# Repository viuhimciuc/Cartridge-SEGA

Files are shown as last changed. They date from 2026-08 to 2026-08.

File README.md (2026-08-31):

# 🎮 Cartridge-SEGA: Sega Genesis Cartridge PCBs 🕹️






An open-source collection of hardware design files for **Sega Genesis / Mega Drive** cartridge PCBs (Printed Circuit Boards). Designed from scratch or reverse-engineered using **KiCad**, this repository provides schemas and layouts for creating custom cartridges, multi-game boards, and memory adapters.

---

## 📂 Repository Structure

The project is organized into several key hardware modules:

*   **`GEN-CART-171-6329A-7147A`** — Replica or custom variant of standard Sega Genesis cartridge PCBs.
*   **`GEN-CART-171-6570A`** — Re-engineered files based on the classic 171-6570A board layout.
*   **`GEN-CART-171-6570A_MultiGames`** — Modded version supporting multiple games on a single cartridge via bank switching or custom routing.
*   **`TSOP_Adapter_M29FxxxF`** — A specialized adapter board converting TSOP flash memory chips (like the M29F series) to DIP/SOP layouts suitable for retro console cartridges.

---

## 🛠️ Built With

*   [KiCad EDA](https://www.kicad.org/) — A Cross-Platform and Open Source Electronics Design Automation Suite.

---

## 📸 Gallery & Visuals

### 🔧 Component Placement / PCB Layout Preview

<p align="center">
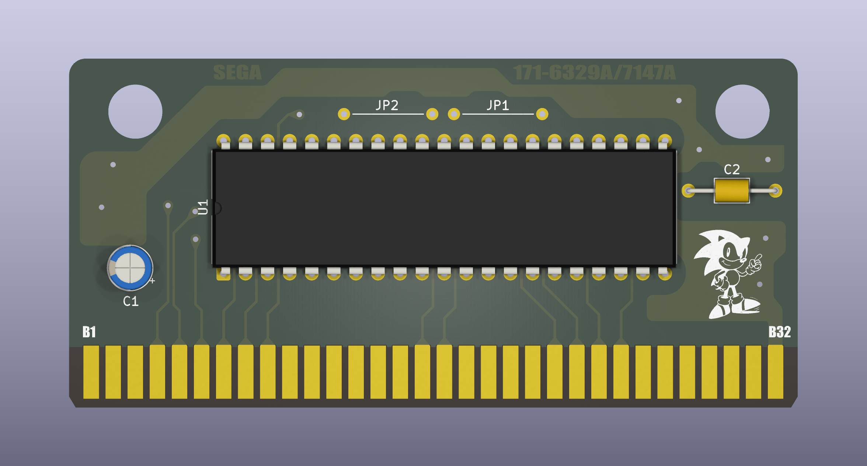
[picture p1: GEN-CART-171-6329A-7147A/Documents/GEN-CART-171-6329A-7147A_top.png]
PCB GEN-CART-171-6329A-7147A
  
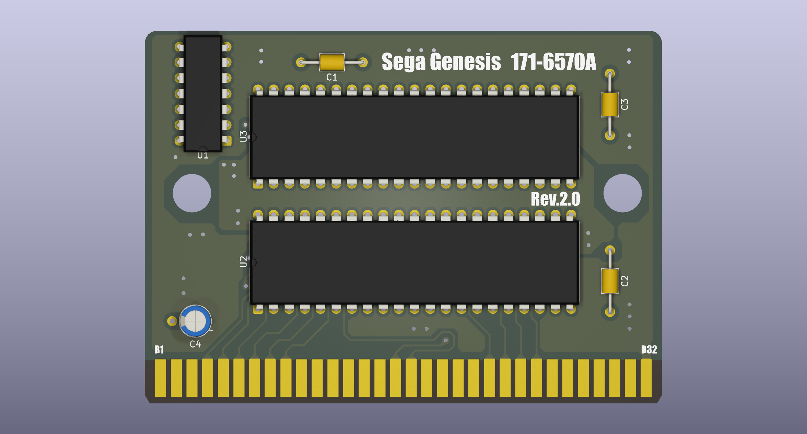
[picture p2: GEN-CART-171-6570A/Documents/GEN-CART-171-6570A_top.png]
PCB GEN-CART-171-6570A
  
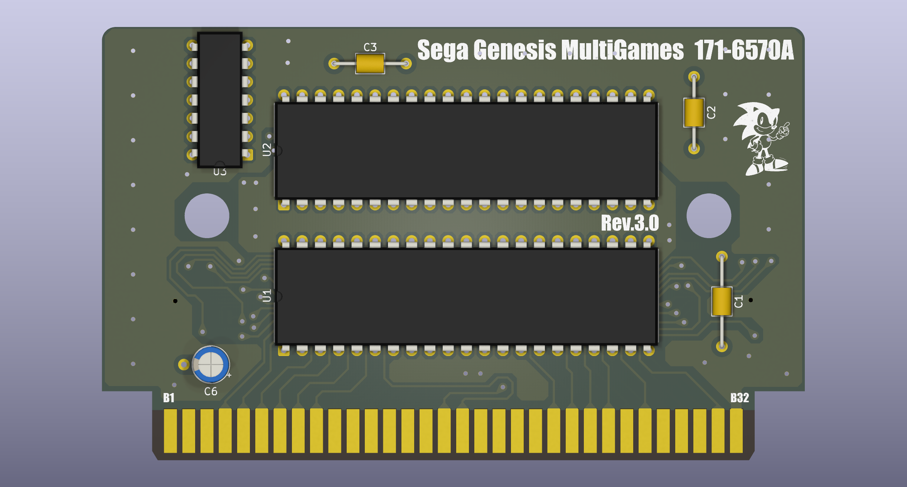
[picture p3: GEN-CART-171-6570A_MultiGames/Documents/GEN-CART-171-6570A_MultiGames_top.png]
PCB GEN-CART-171-6570A MultiGames
  
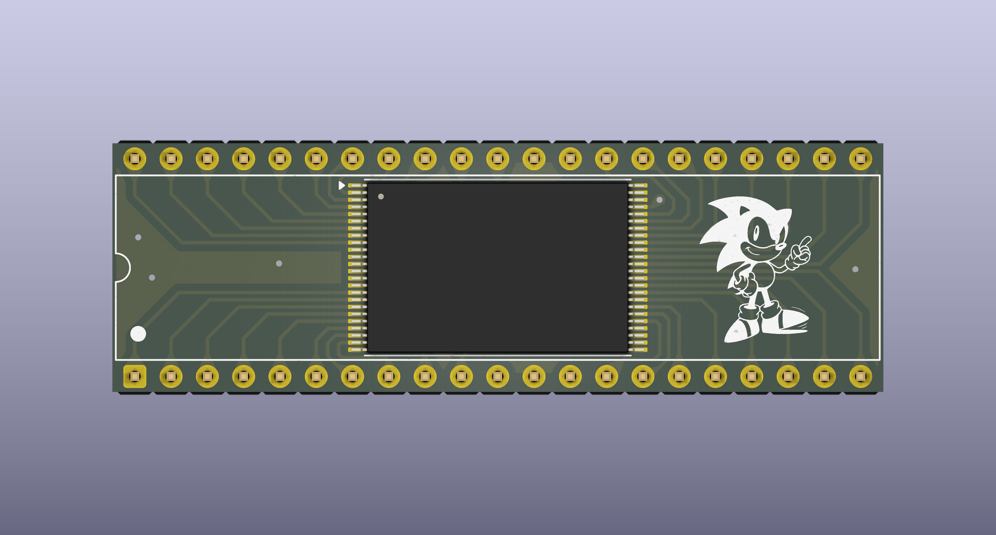
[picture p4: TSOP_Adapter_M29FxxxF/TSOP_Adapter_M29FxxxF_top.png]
PCB TSOP Adapter M29FxxxF
  
</p>

---

## 🚀 Getting Started

### 📋 Prerequisites
To open, edit, or export production files (Gerbers) from this project, you need:
*   **KiCad 7.0 or newer** (Recommended)

### 📥 Cloning the Repository
```bash
git clone https://github.com/viuhimciuc/Cartridge-SEGA.git
```

### ⚙️ How to Generate Gerber Files for Manufacturing
1. Open the `.kicad_pro` project file from any folder in KiCad.
2. Open the **PCB Editor** (`.kicad_pcb`).
3. Go to **File** -> **Fabrication Outputs** -> **Gerbers (.gbr)**.
4. Set your output directory and click **Plot**.
5. Click **Generate Drill Files** to export standard NC drill configurations.
6. Zip all generated files and send them to your preferred PCB manufacturer (e.g., JLCPCB, PCBWay).

---

## 🤝 Contributing

Contributions, bug reports, and hardware improvements are highly welcome! 
1. **Fork** the Project.
2. Create your **Feature Branch** (`git checkout -b feature/AmazingFeature`).
3. **Commit** your Changes (`git commit -m 'Add some AmazingFeature'`).
4. **Push** to the Branch (`git push origin feature/AmazingFeature`).
5. Open a **Pull Request**.

---

## 📄 License

This project is licensed under the MIT License - see the [LICENSE](LICENSE) file for details.

---

<p align="center"> Developed with ❤️ for the Retro Gaming Community </p>

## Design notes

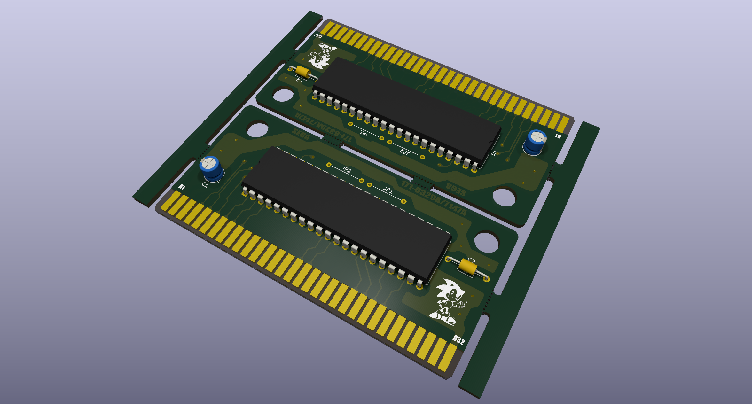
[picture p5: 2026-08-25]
GEN-CART-171-6329A-7147A/panelize_GEN-CART-171-6329A-7147A/panelize_GEN-CART-171-6329A-7147A.png

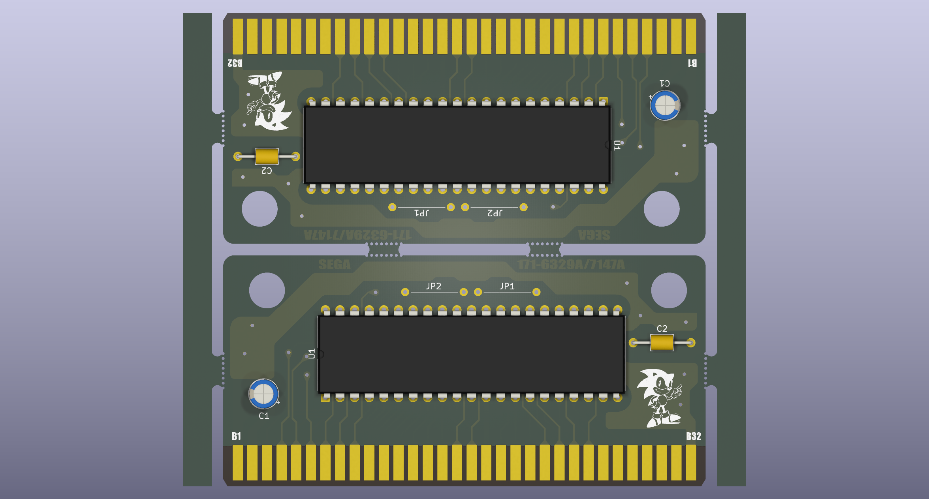
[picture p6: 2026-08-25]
GEN-CART-171-6329A-7147A/panelize_GEN-CART-171-6329A-7147A/panelize_GEN-CART-171-6329A-7147A_top.png

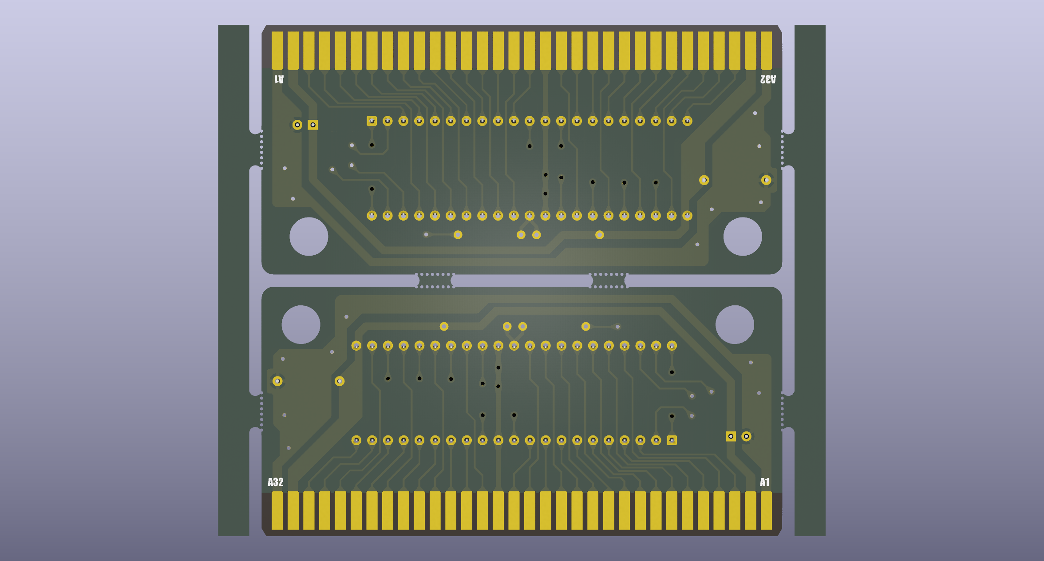
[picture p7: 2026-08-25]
GEN-CART-171-6329A-7147A/panelize_GEN-CART-171-6329A-7147A/panelize_GEN-CART-171-6329A-7147A_bottom.png

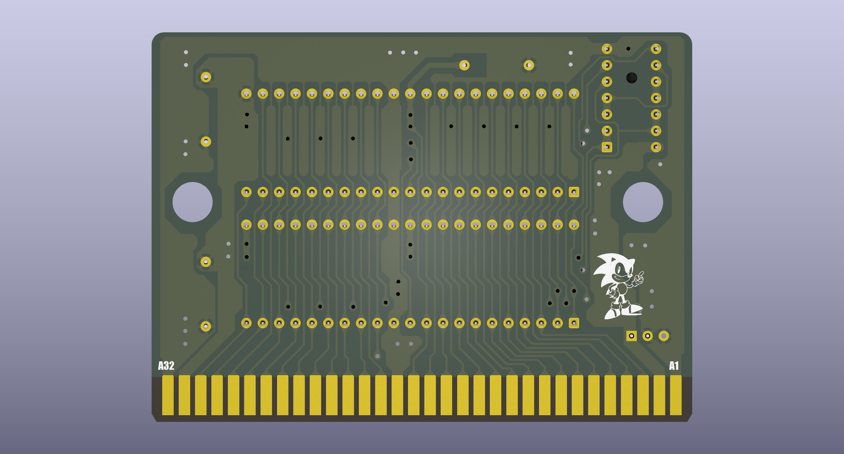
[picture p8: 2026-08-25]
GEN-CART-171-6570A/Documents/GEN-CART-171-6570A__bottom.png

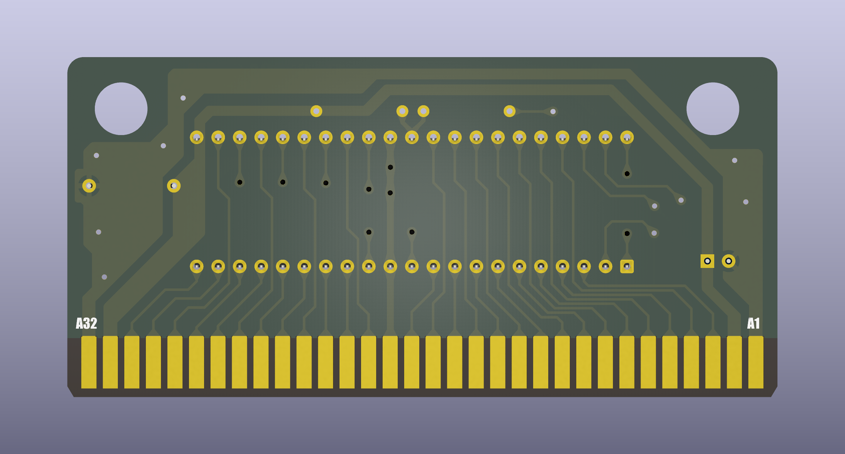
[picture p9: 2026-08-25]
GEN-CART-171-6329A-7147A/Documents/GEN-CART-171-6329A-7147A_bottom.png

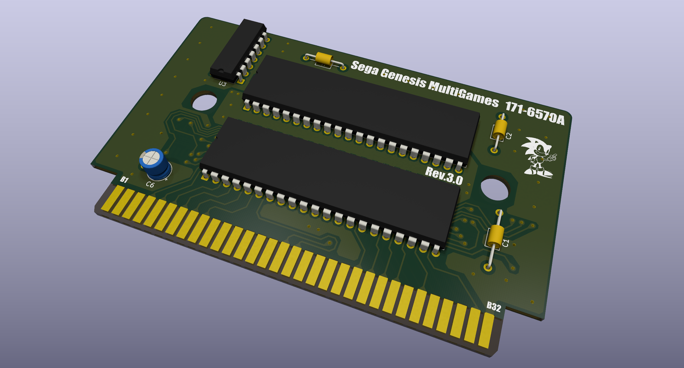
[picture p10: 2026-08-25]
GEN-CART-171-6570A_MultiGames/Documents/GEN-CART-171-6570A_MultiGames.png

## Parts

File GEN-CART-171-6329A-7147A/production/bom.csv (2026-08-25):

Designator | Footprint | Quantity | Value | LCSC Part #
C1 | CP_Radial_D5.0mm_P2.50mm | 1 | 47uF 16V
C2 | C_Axial_L3.8mm_D2.6mm_P10.00mm_Horizontal | 1 | 0.1uF
CATR1 | PCB_revA-CART-64-2.54-CONN | 1 | EDGE-CONN-64-PIN-PCB_BASIC_revA
JP1, JP2 | Jumper_P10.16mm_D0.7mm | 2 | Jumper_2_Open
U1 | DIP-42_W15.24mm | 1 | MX29F1615

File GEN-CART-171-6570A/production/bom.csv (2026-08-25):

Designator | Footprint | Quantity | Value | LCSC Part #
C1, C2, C3 | C_Axial_L3.8mm_D2.6mm_P10.00mm_Horizontal | 3 | 0.1uF
C4 | CP_Radial_D5.0mm_P2.50mm | 1 | 47uF 16V
CATR1 | PCB_revB-CART-64-2.54-CONN | 1 | EDGE-CONN-64-PIN-PCB_BASIC_revB
U1 | DIP-14_W7.62mm | 1 | 74HC00
U2, U3 | DIP-42_W15.24mm | 2 | MX29F1615

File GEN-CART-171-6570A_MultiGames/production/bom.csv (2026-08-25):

Designator | Footprint | Quantity | Value | LCSC Part #
C1 | C_Axial_L3.8mm_D2.6mm_P12.50mm_Horizontal | 1 | 0.1uF
C2, C3 | C_Axial_L3.8mm_D2.6mm_P10.00mm_Horizontal | 2 | 0.1uF
C4, C5 | 0805 | 2 | 0.1uF
C6 | CP_Radial_D5.0mm_P2.50mm | 1 | 47uF 16V
CATR1 | PCB_revC-CART-64-2.54-CONN | 1 | EDGE-CONN-64-PIN-PCB_BASIC_revC
U1, U2 | DIP-42_W15.24mm | 2 | MX29F1615
U3 | DIP-14_W7.62mm | 1 | 74HC00
U4 | SOIC-16_3.9x9.9mm_P1.27mm | 1 | 74LS174
U5 | SOIC-14_3.9x8.7mm_P1.27mm | 1 | 74LS32

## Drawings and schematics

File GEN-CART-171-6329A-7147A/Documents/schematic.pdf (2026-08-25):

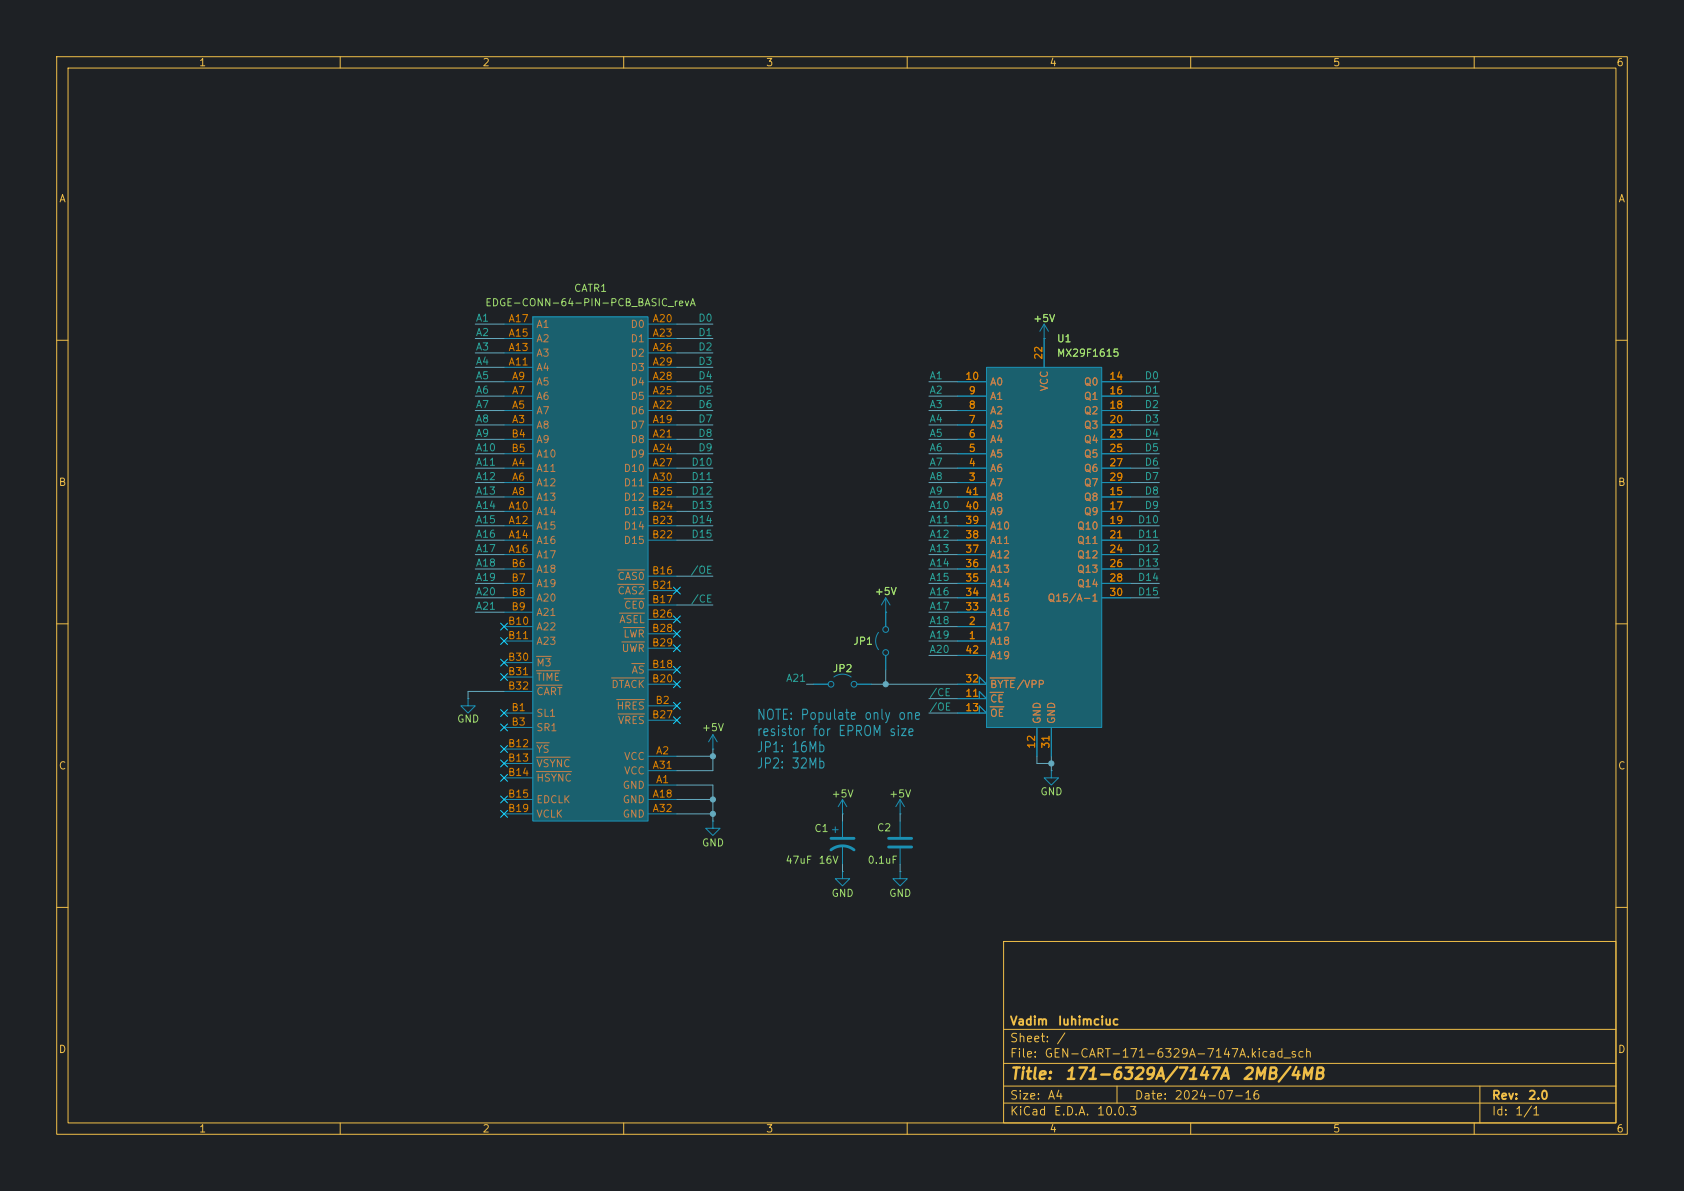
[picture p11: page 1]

Size: A4 | Rev: 2.0
KiCad E.D.A. 10.0.3 | Id: 1/1

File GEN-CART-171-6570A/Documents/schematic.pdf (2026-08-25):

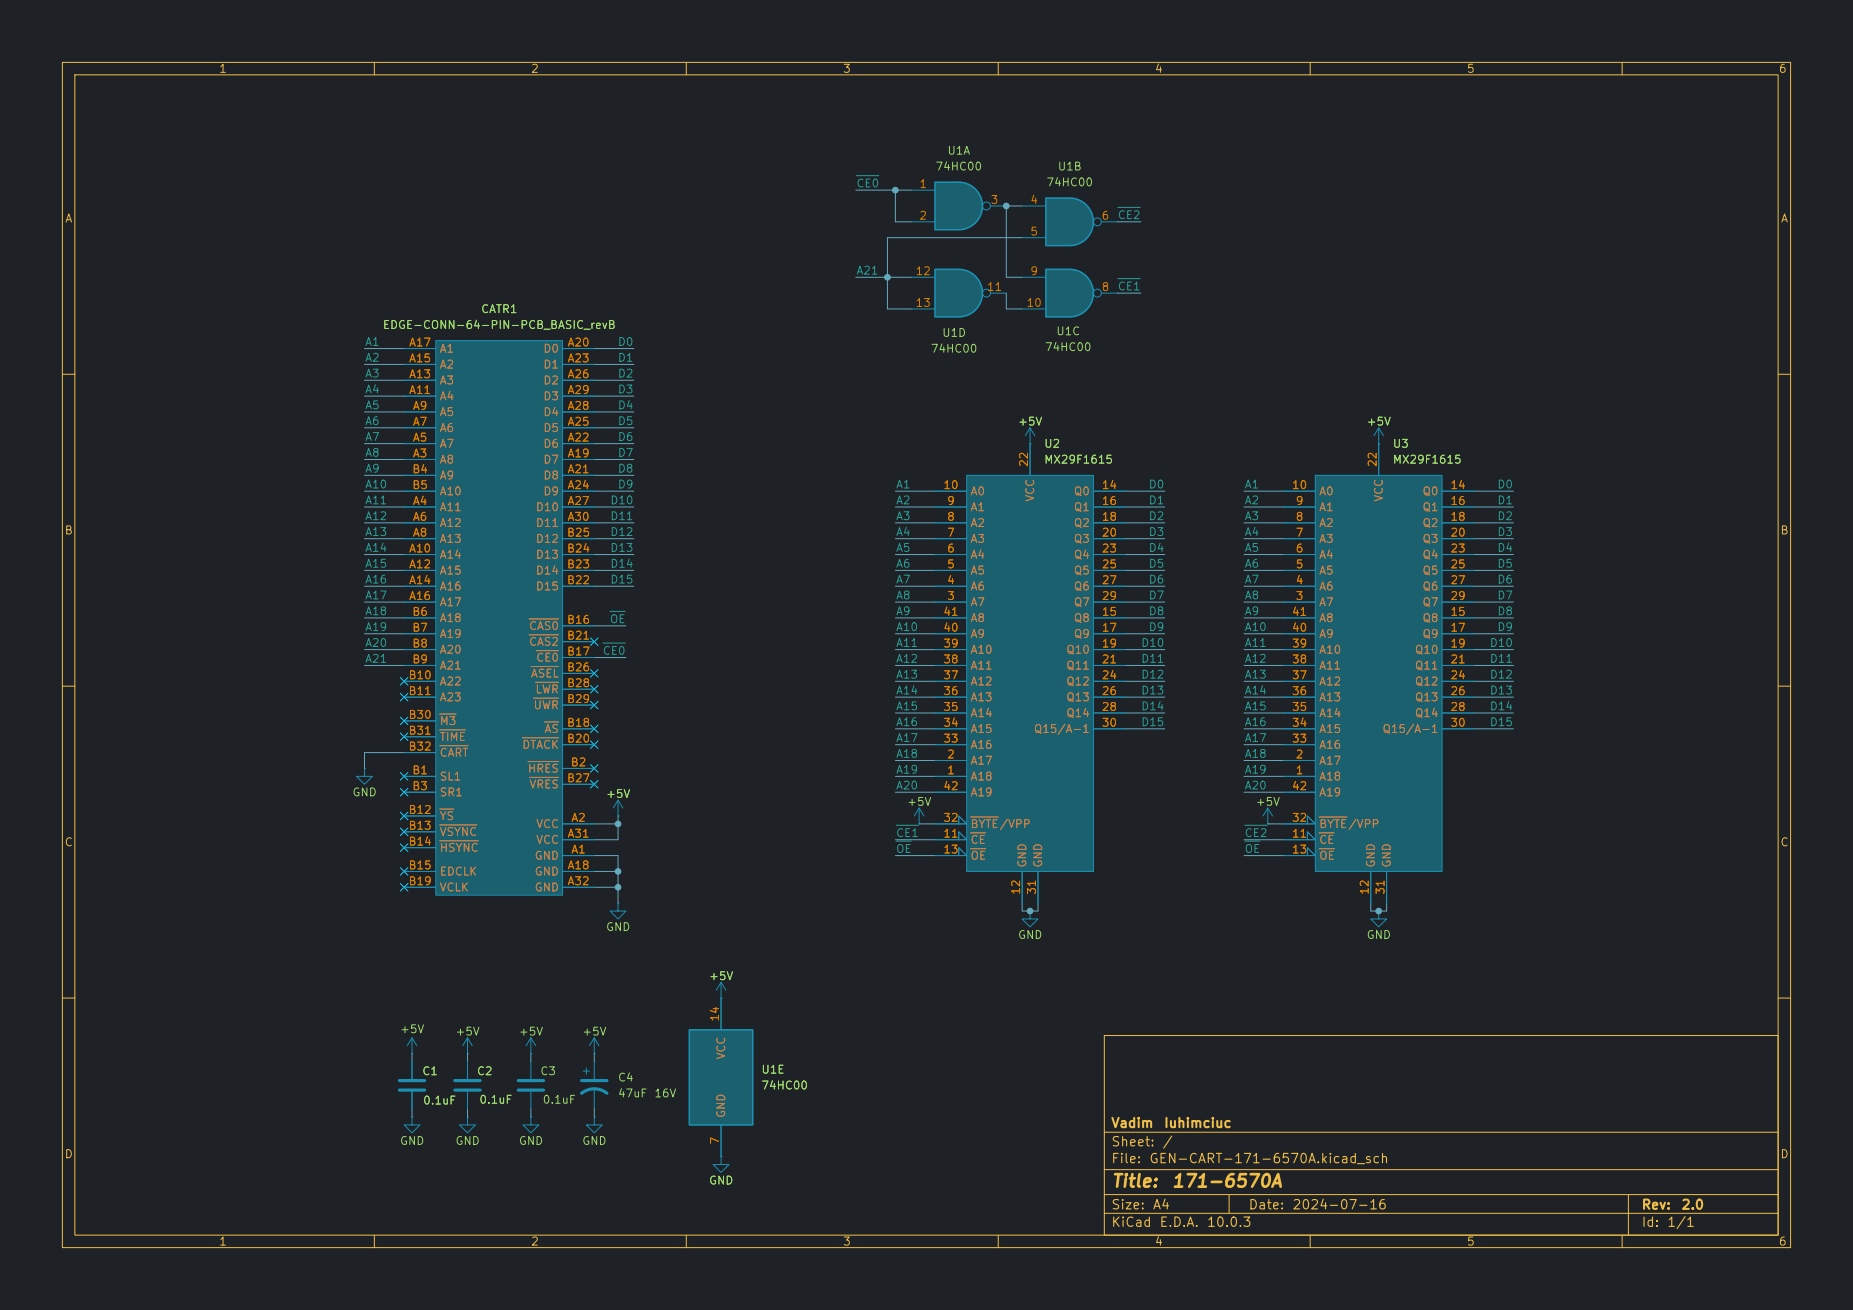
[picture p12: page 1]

Size: A4 | Rev: 2.0
KiCad E.D.A. 10.0.3 | Id: 1/1

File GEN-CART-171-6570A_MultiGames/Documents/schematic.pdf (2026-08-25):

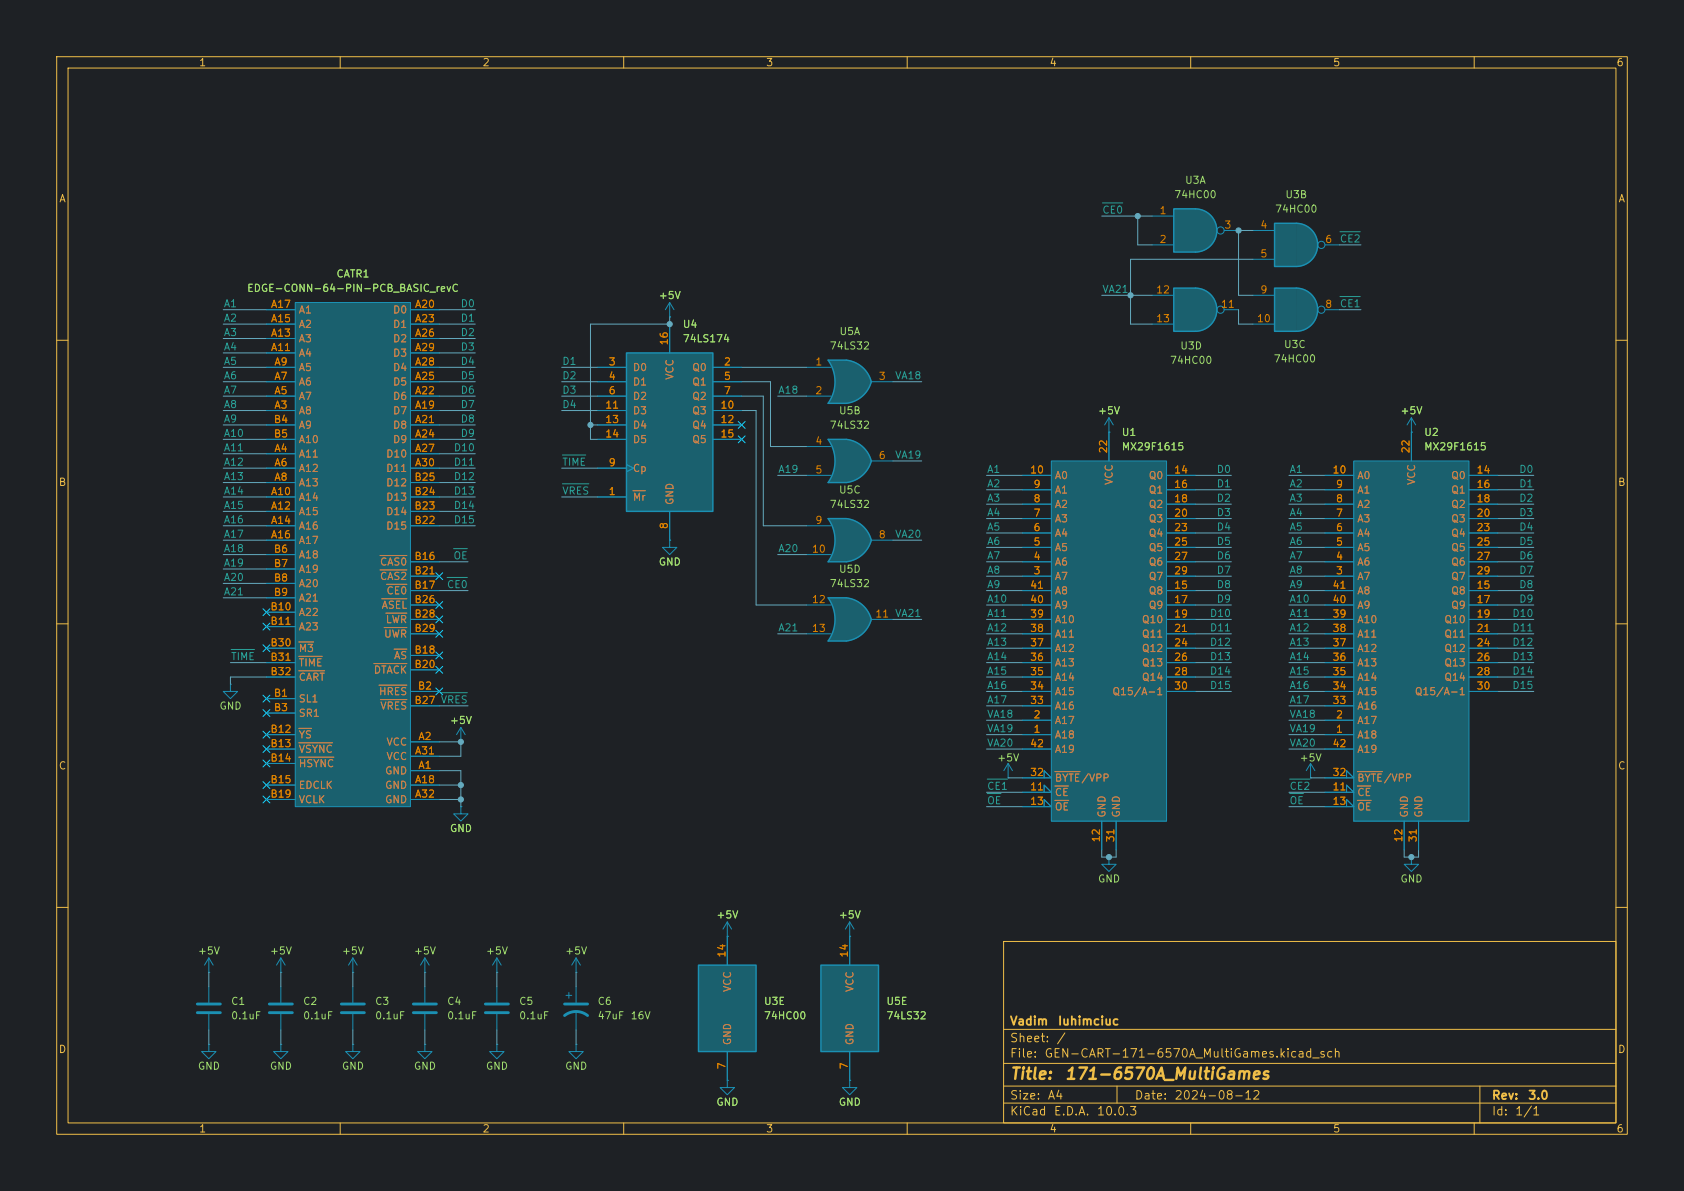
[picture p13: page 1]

7 VCC 14 GND +5V GND U3E 74HC00 GND

Size: A4 | Rev: 3.0
KiCad E.D.A. 10.0.3 | Id: 1/1

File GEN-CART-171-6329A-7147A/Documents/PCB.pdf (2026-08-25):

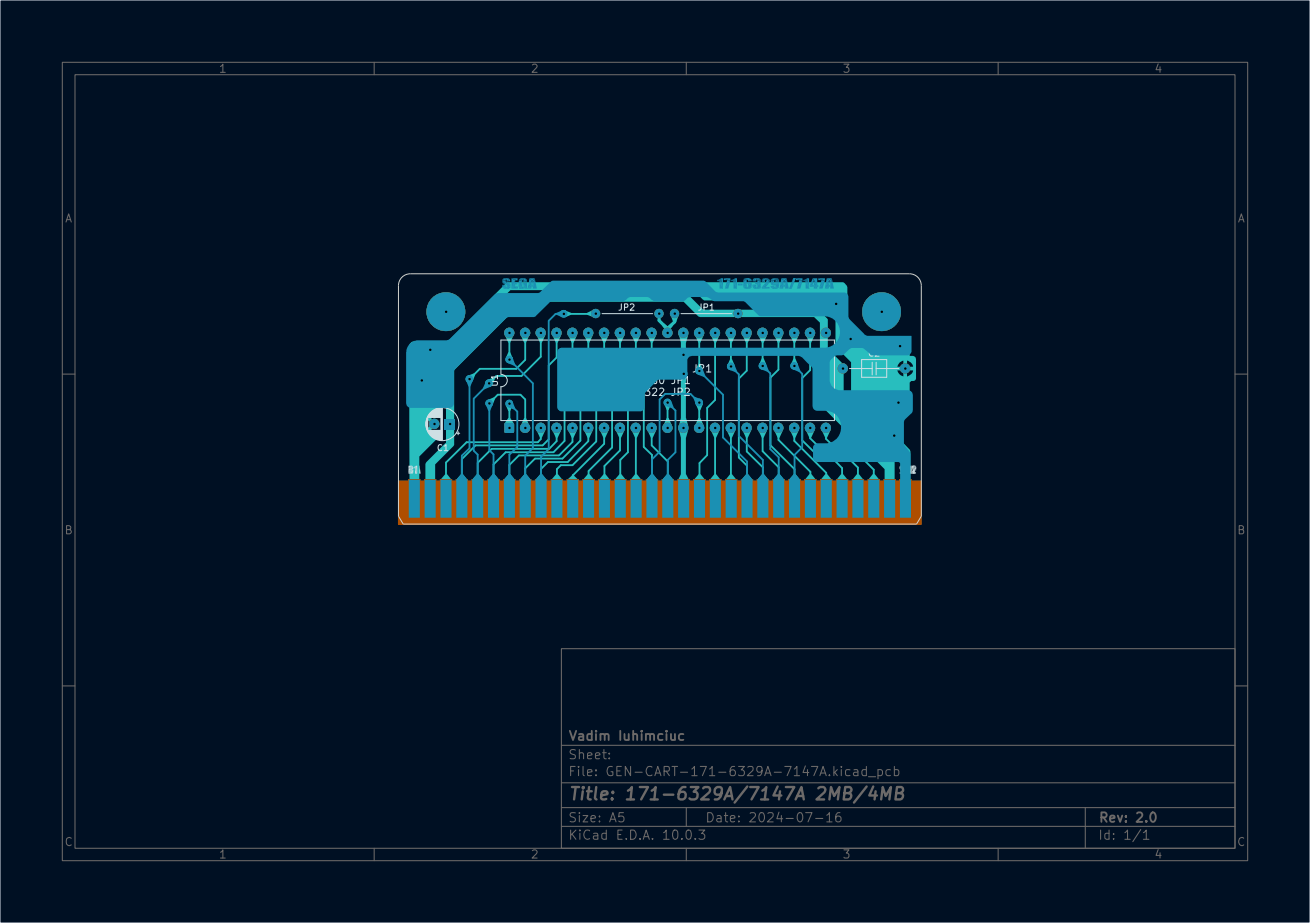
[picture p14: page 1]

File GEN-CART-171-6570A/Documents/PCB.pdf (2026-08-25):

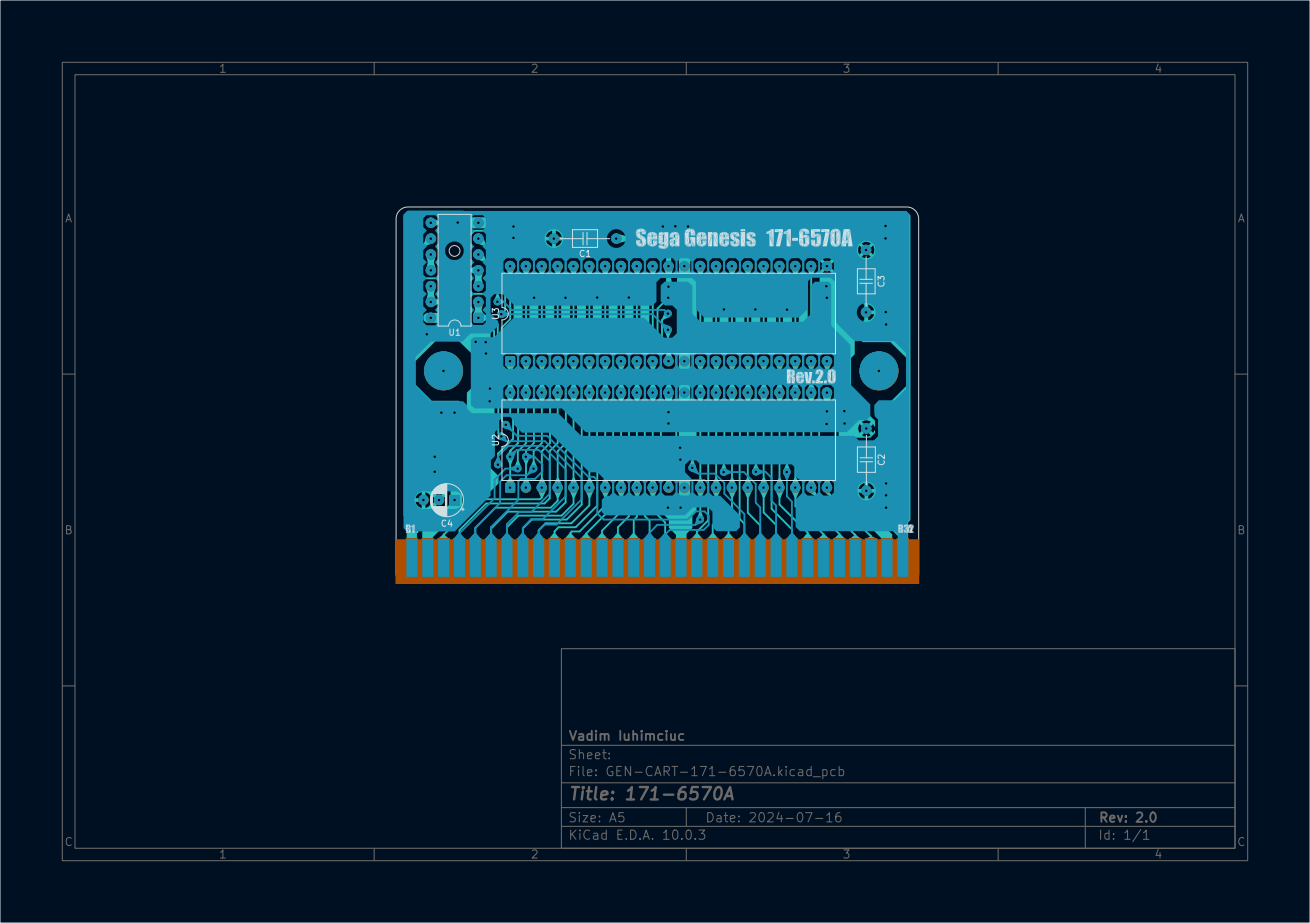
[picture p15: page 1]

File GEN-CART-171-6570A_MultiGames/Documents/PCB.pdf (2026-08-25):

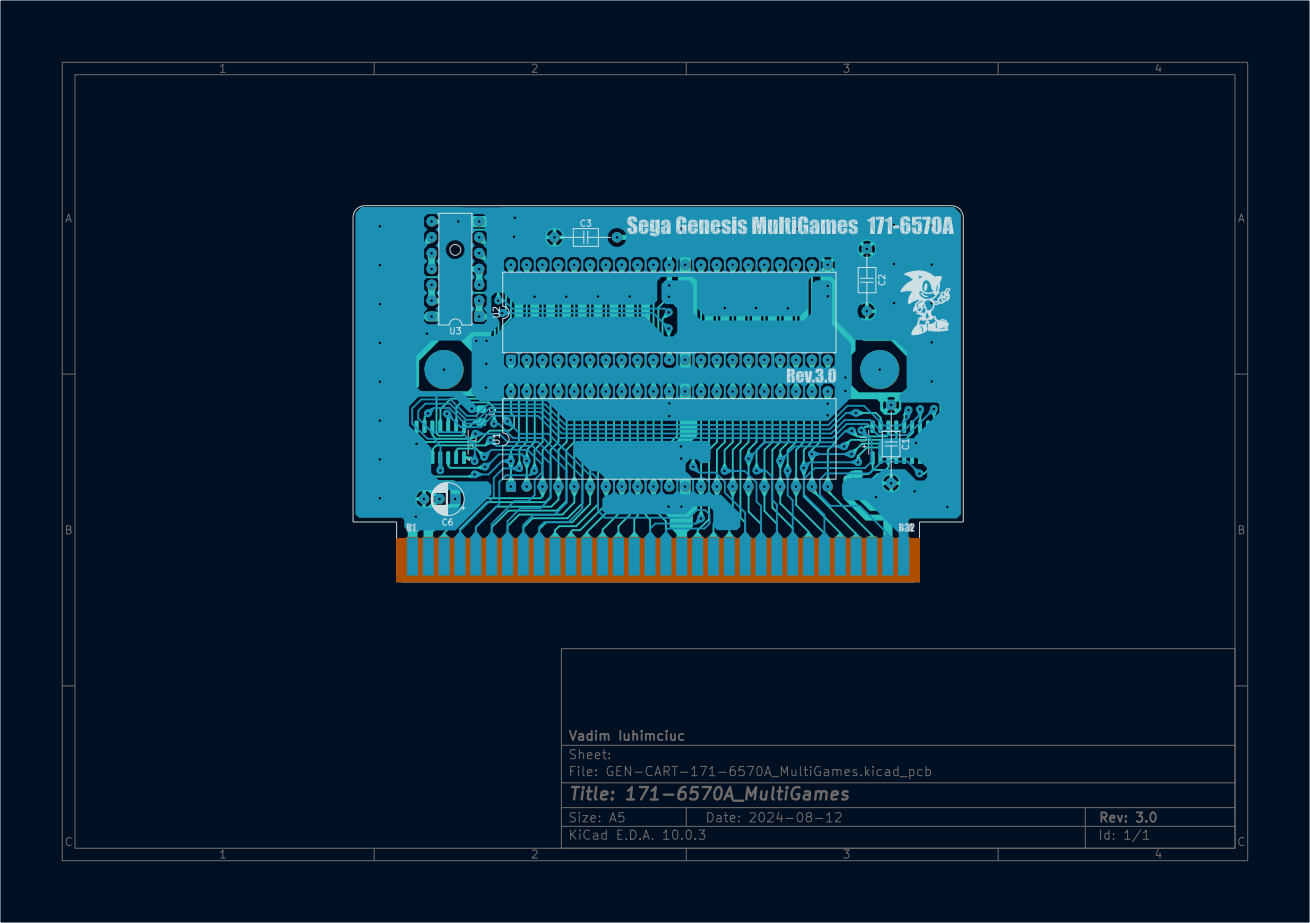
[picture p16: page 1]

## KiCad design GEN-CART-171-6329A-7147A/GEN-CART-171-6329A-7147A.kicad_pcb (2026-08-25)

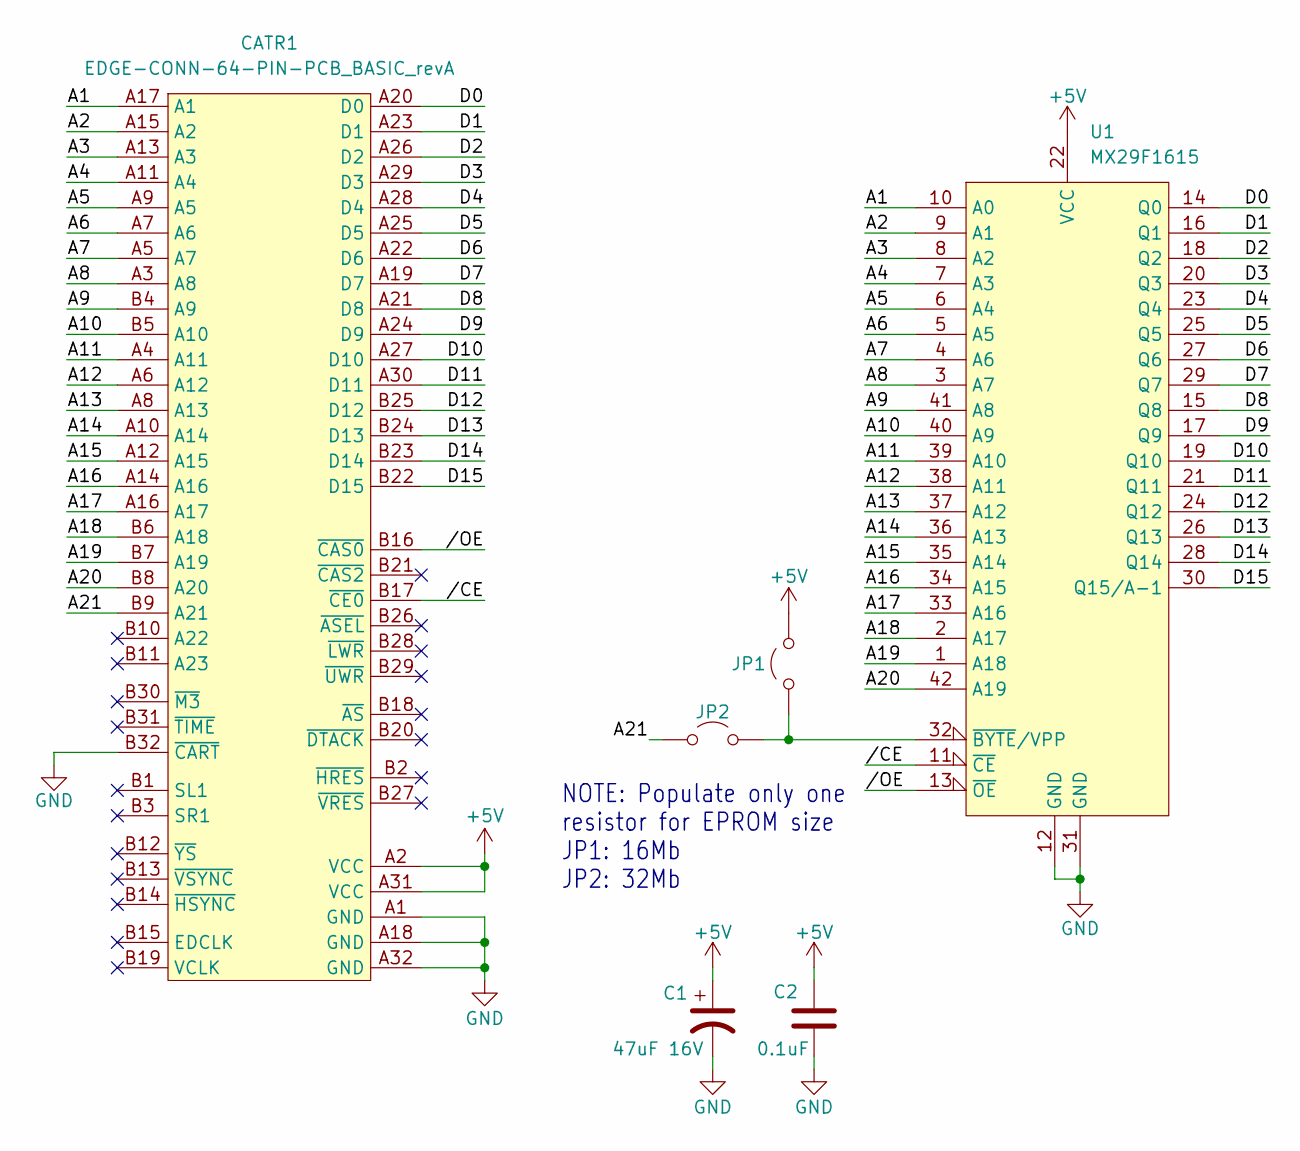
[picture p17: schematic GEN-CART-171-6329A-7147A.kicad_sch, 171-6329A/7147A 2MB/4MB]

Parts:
C1: 47uF 16V; CP_Radial_D5.0mm_P2.50mm
C2: 0.1uF; C_Axial_L3.8mm_D2.6mm_P10.00mm_Horizontal
CATR1: EDGE-CONN-64-PIN-PCB_BASIC_revA; PCB_revA-CART-64-2.54-CONN
JP1, JP2: Jumper_2_Open; Jumper_P10.16mm_D0.7mm
U1: MX29F1615; DIP-42_W15.24mm

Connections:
+5V: C1.1, C2.1, CATR1.A2 (VCC), CATR1.A31 (VCC), JP1.2 (B), U1.22 (VCC)
/A1: CATR1.A17 (A1), U1.10 (A0)
/A2: CATR1.A15 (A2), U1.9 (A1)
/A3: CATR1.A13 (A3), U1.8 (A2)
/A4: CATR1.A11 (A4), U1.7 (A3)
/A5: CATR1.A9 (A5), U1.6 (A4)
/A6: CATR1.A7 (A6), U1.5 (A5)
/A7: CATR1.A5 (A7), U1.4 (A6)
/A8: CATR1.A3 (A8), U1.3 (A7)
/A9: CATR1.B4 (A9), U1.41 (A8)
/A10: CATR1.B5 (A10), U1.40 (A9)
/A11: CATR1.A4 (A11), U1.39 (A10)
/A12: CATR1.A6 (A12), U1.38 (A11)
/A13: CATR1.A8 (A13), U1.37 (A12)
/A14: CATR1.A10 (A14), U1.36 (A13)
/A15: CATR1.A12 (A15), U1.35 (A14)
/A16: CATR1.A14 (A16), U1.34 (A15)
/A17: CATR1.A16 (A17), U1.33 (A16)
/A18: CATR1.B6 (A18), U1.2 (A17)
/A19: CATR1.B7 (A19), U1.1 (A18)
/A20: CATR1.B8 (A20), U1.42 (A19)
/A21: CATR1.B9 (A21), JP2.1 (A)
/D0: CATR1.A20 (D0), U1.14 (Q0)
/D1: CATR1.A23 (D1), U1.16 (Q1)
/D2: CATR1.A26 (D2), U1.18 (Q2)
/D3: CATR1.A29 (D3), U1.20 (Q3)
/D4: CATR1.A28 (D4), U1.23 (Q4)
/D5: CATR1.A25 (D5), U1.25 (Q5)
/D6: CATR1.A22 (D6), U1.27 (Q6)
/D7: CATR1.A19 (D7), U1.29 (Q7)
/D8: CATR1.A21 (D8), U1.15 (Q8)
/D9: CATR1.A24 (D9), U1.17 (Q9)
/D10: CATR1.A27 (D10), U1.19 (Q10)
/D11: CATR1.A30 (D11), U1.21 (Q11)
/D12: CATR1.B25 (D12), U1.24 (Q12)
/D13: CATR1.B24 (D13), U1.26 (Q13)
/D14: CATR1.B23 (D14), U1.28 (Q14)
/D15: CATR1.B22 (D15), U1.30 (Q15/A-1)
//CE: CATR1.B17 (~CE0), U1.11 (~CE)
//OE: CATR1.B16 (~CAS0), U1.13 (~OE)
GND: C1.2, C2.2, CATR1.A1 (GND), CATR1.A18 (GND), CATR1.A32 (GND), CATR1.B32 (~CART), U1.12 (GND), U1.31 (GND)
unnamed: JP1.1 (A), JP2.2 (B), U1.32 (~BYTE/VPP)

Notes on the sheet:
NOTE: Populate only one resistor for EPROM size JP1: 16Mb JP2: 32Mb

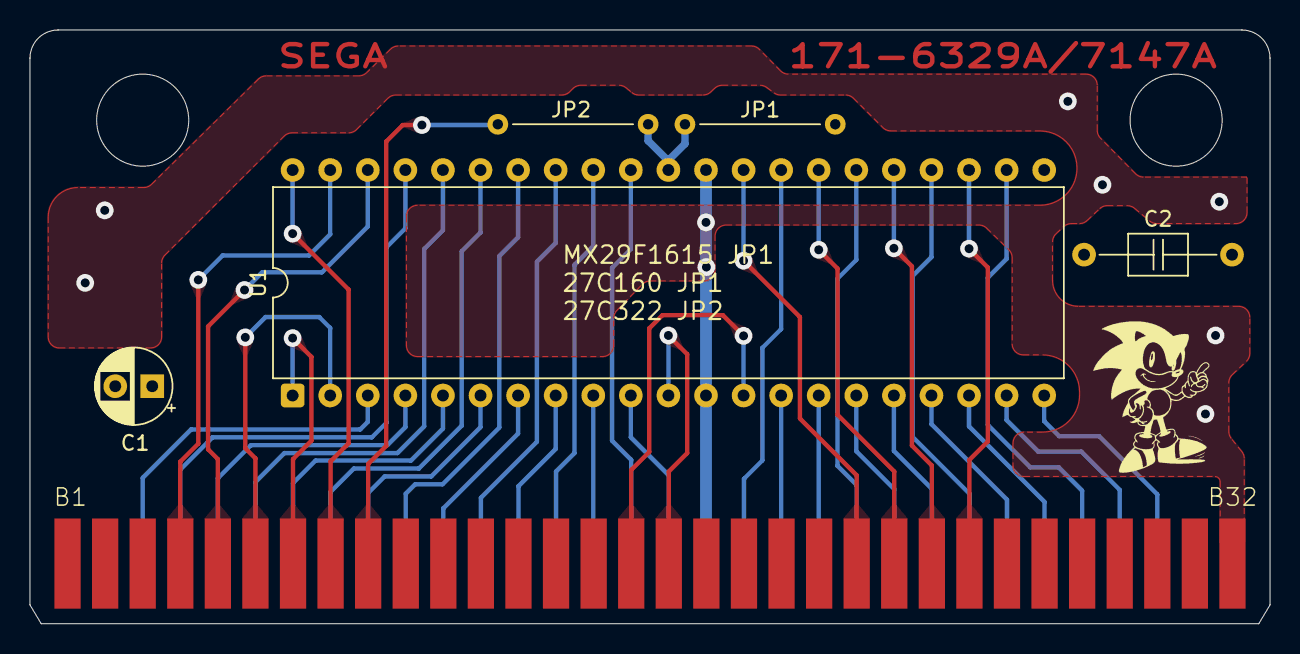
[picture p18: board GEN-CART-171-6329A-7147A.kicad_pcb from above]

Board: 2 copper layers, 83.8 x 40.1 mm, 6 parts (0 on the bottom side), 42 nets.

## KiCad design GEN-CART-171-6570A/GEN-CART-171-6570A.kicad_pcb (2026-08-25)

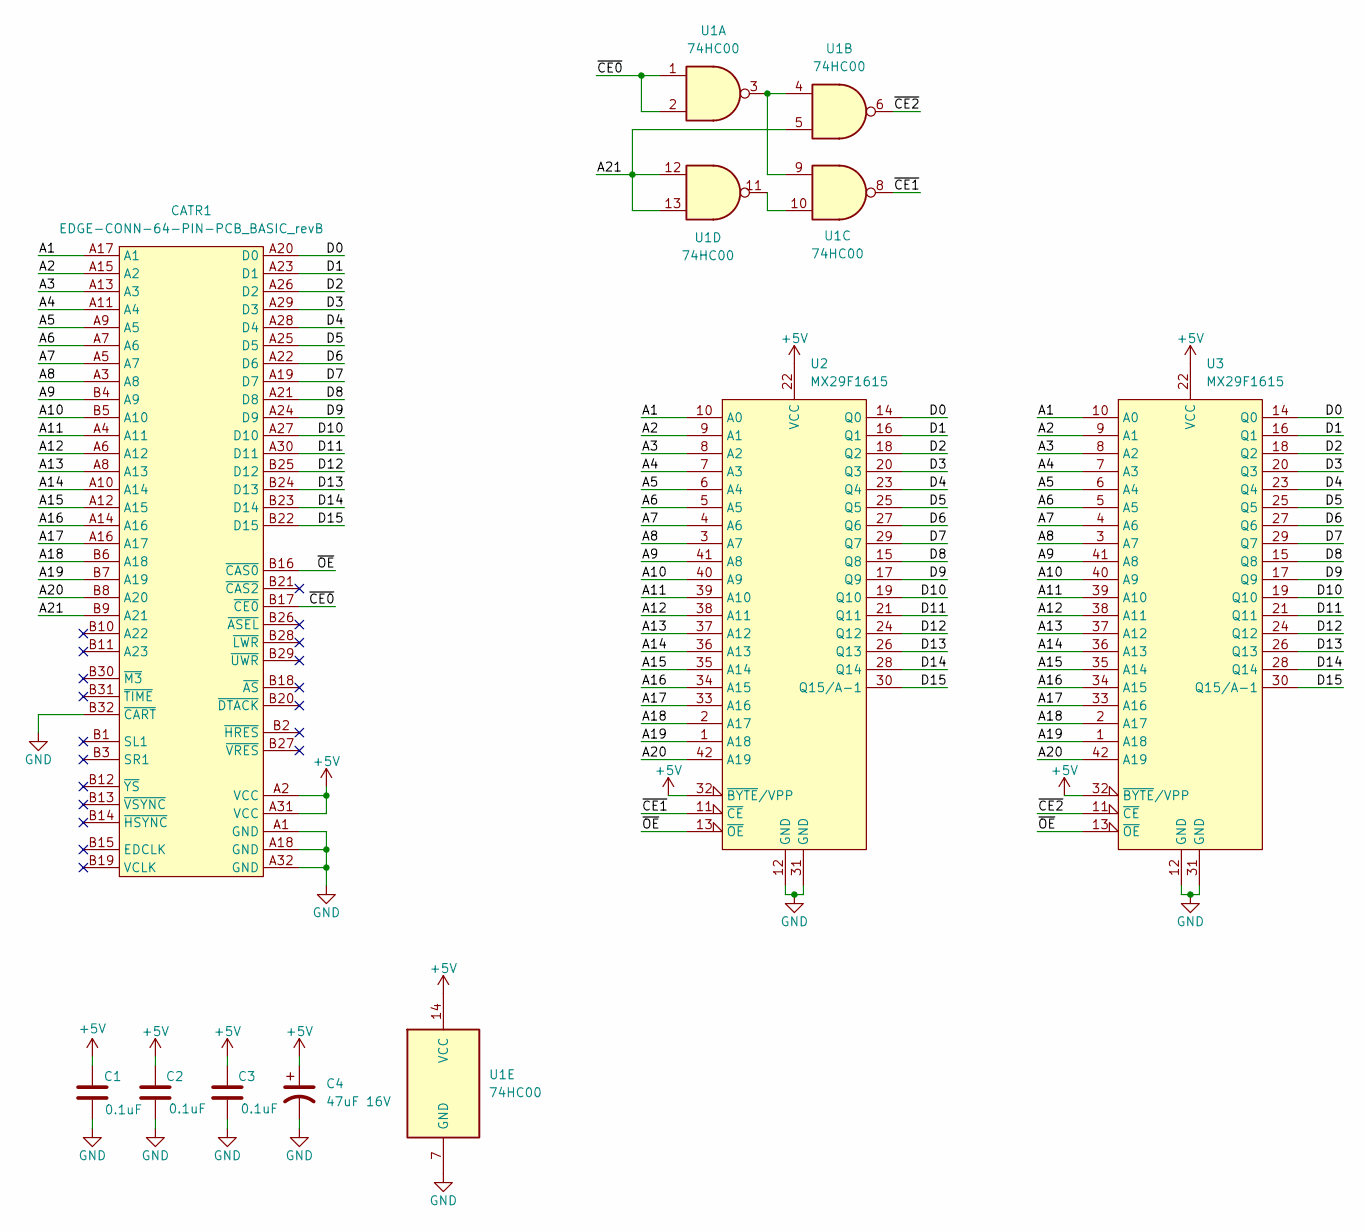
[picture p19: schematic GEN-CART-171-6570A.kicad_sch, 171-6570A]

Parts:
C1, C2, C3: 0.1uF; C_Axial_L3.8mm_D2.6mm_P10.00mm_Horizontal
C4: 47uF 16V; CP_Radial_D5.0mm_P2.50mm
CATR1: EDGE-CONN-64-PIN-PCB_BASIC_revB; PCB_revB-CART-64-2.54-CONN
U1: 74HC00; DIP-14_W7.62mm
U2, U3: MX29F1615; DIP-42_W15.24mm

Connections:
+5V: C1.1, C2.1, C3.1, C4.1, CATR1.A2 (VCC), CATR1.A31 (VCC), U1.14 (VCC), U2.22 (VCC), U2.32 (~BYTE/VPP), U3.22 (VCC), U3.32 (~BYTE/VPP)
/A1: CATR1.A17 (A1), U2.10 (A0), U3.10 (A0)
/A2: CATR1.A15 (A2), U2.9 (A1), U3.9 (A1)
/A3: CATR1.A13 (A3), U2.8 (A2), U3.8 (A2)
/A4: CATR1.A11 (A4), U2.7 (A3), U3.7 (A3)
/A5: CATR1.A9 (A5), U2.6 (A4), U3.6 (A4)
/A6: CATR1.A7 (A6), U2.5 (A5), U3.5 (A5)
/A7: CATR1.A5 (A7), U2.4 (A6), U3.4 (A6)
/A8: CATR1.A3 (A8), U2.3 (A7), U3.3 (A7)
/A9: CATR1.B4 (A9), U2.41 (A8), U3.41 (A8)
/A10: CATR1.B5 (A10), U2.40 (A9), U3.40 (A9)
/A11: CATR1.A4 (A11), U2.39 (A10), U3.39 (A10)
/A12: CATR1.A6 (A12), U2.38 (A11), U3.38 (A11)
/A13: CATR1.A8 (A13), U2.37 (A12), U3.37 (A12)
/A14: CATR1.A10 (A14), U2.36 (A13), U3.36 (A13)
/A15: CATR1.A12 (A15), U2.35 (A14), U3.35 (A14)
/A16: CATR1.A14 (A16), U2.34 (A15), U3.34 (A15)
/A17: CATR1.A16 (A17), U2.33 (A16), U3.33 (A16)
/A18: CATR1.B6 (A18), U2.2 (A17), U3.2 (A17)
/A19: CATR1.B7 (A19), U2.1 (A18), U3.1 (A18)
/A20: CATR1.B8 (A20), U2.42 (A19), U3.42 (A19)
/A21: CATR1.B9 (A21), U1.5, U1.12, U1.13
/D0: CATR1.A20 (D0), U2.14 (Q0), U3.14 (Q0)
/D1: CATR1.A23 (D1), U2.16 (Q1), U3.16 (Q1)
/D2: CATR1.A26 (D2), U2.18 (Q2), U3.18 (Q2)
/D3: CATR1.A29 (D3), U2.20 (Q3), U3.20 (Q3)
/D4: CATR1.A28 (D4), U2.23 (Q4), U3.23 (Q4)
/D5: CATR1.A25 (D5), U2.25 (Q5), U3.25 (Q5)
/D6: CATR1.A22 (D6), U2.27 (Q6), U3.27 (Q6)
/D7: CATR1.A19 (D7), U2.29 (Q7), U3.29 (Q7)
/D8: CATR1.A21 (D8), U2.15 (Q8), U3.15 (Q8)
/D9: CATR1.A24 (D9), U2.17 (Q9), U3.17 (Q9)
/D10: CATR1.A27 (D10), U2.19 (Q10), U3.19 (Q10)
/D11: CATR1.A30 (D11), U2.21 (Q11), U3.21 (Q11)
/D12: CATR1.B25 (D12), U2.24 (Q12), U3.24 (Q12)
/D13: CATR1.B24 (D13), U2.26 (Q13), U3.26 (Q13)
/D14: CATR1.B23 (D14), U2.28 (Q14), U3.28 (Q14)
/D15: CATR1.B22 (D15), U2.30 (Q15/A-1), U3.30 (Q15/A-1)
/~CE0: CATR1.B17 (~CE0), U1.1, U1.2
/~CE1: U1.8, U2.11 (~CE)
/~CE2: U1.6, U3.11 (~CE)
/~OE: CATR1.B16 (~CAS0), U2.13 (~OE), U3.13 (~OE)
GND: C1.2, C2.2, C3.2, C4.2, CATR1.A1 (GND), CATR1.A18 (GND), CATR1.A32 (GND), CATR1.B32 (~CART), U1.7 (GND), U2.12 (GND), U2.31 (GND), U3.12 (GND), U3.31 (GND); also elsewhere on the board
unnamed: U1.3, U1.4, U1.9
unnamed: U1.10, U1.11

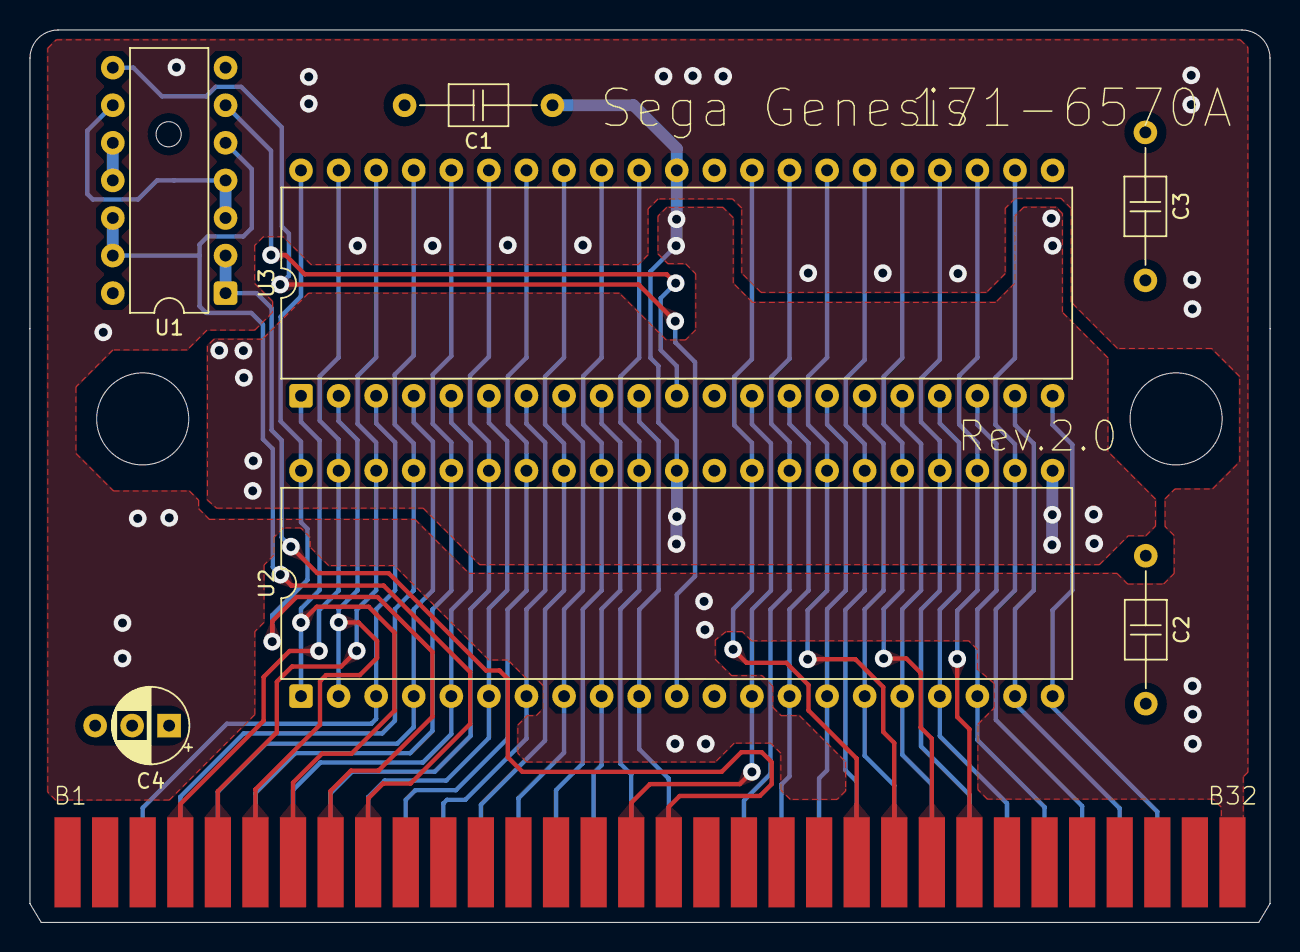
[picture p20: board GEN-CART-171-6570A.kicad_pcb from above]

Board: 2 copper layers, 83.8 x 60.3 mm, 9 parts (0 on the bottom side), 45 nets.

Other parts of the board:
GND: (no value)

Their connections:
GND: GND.2; also elsewhere on the board

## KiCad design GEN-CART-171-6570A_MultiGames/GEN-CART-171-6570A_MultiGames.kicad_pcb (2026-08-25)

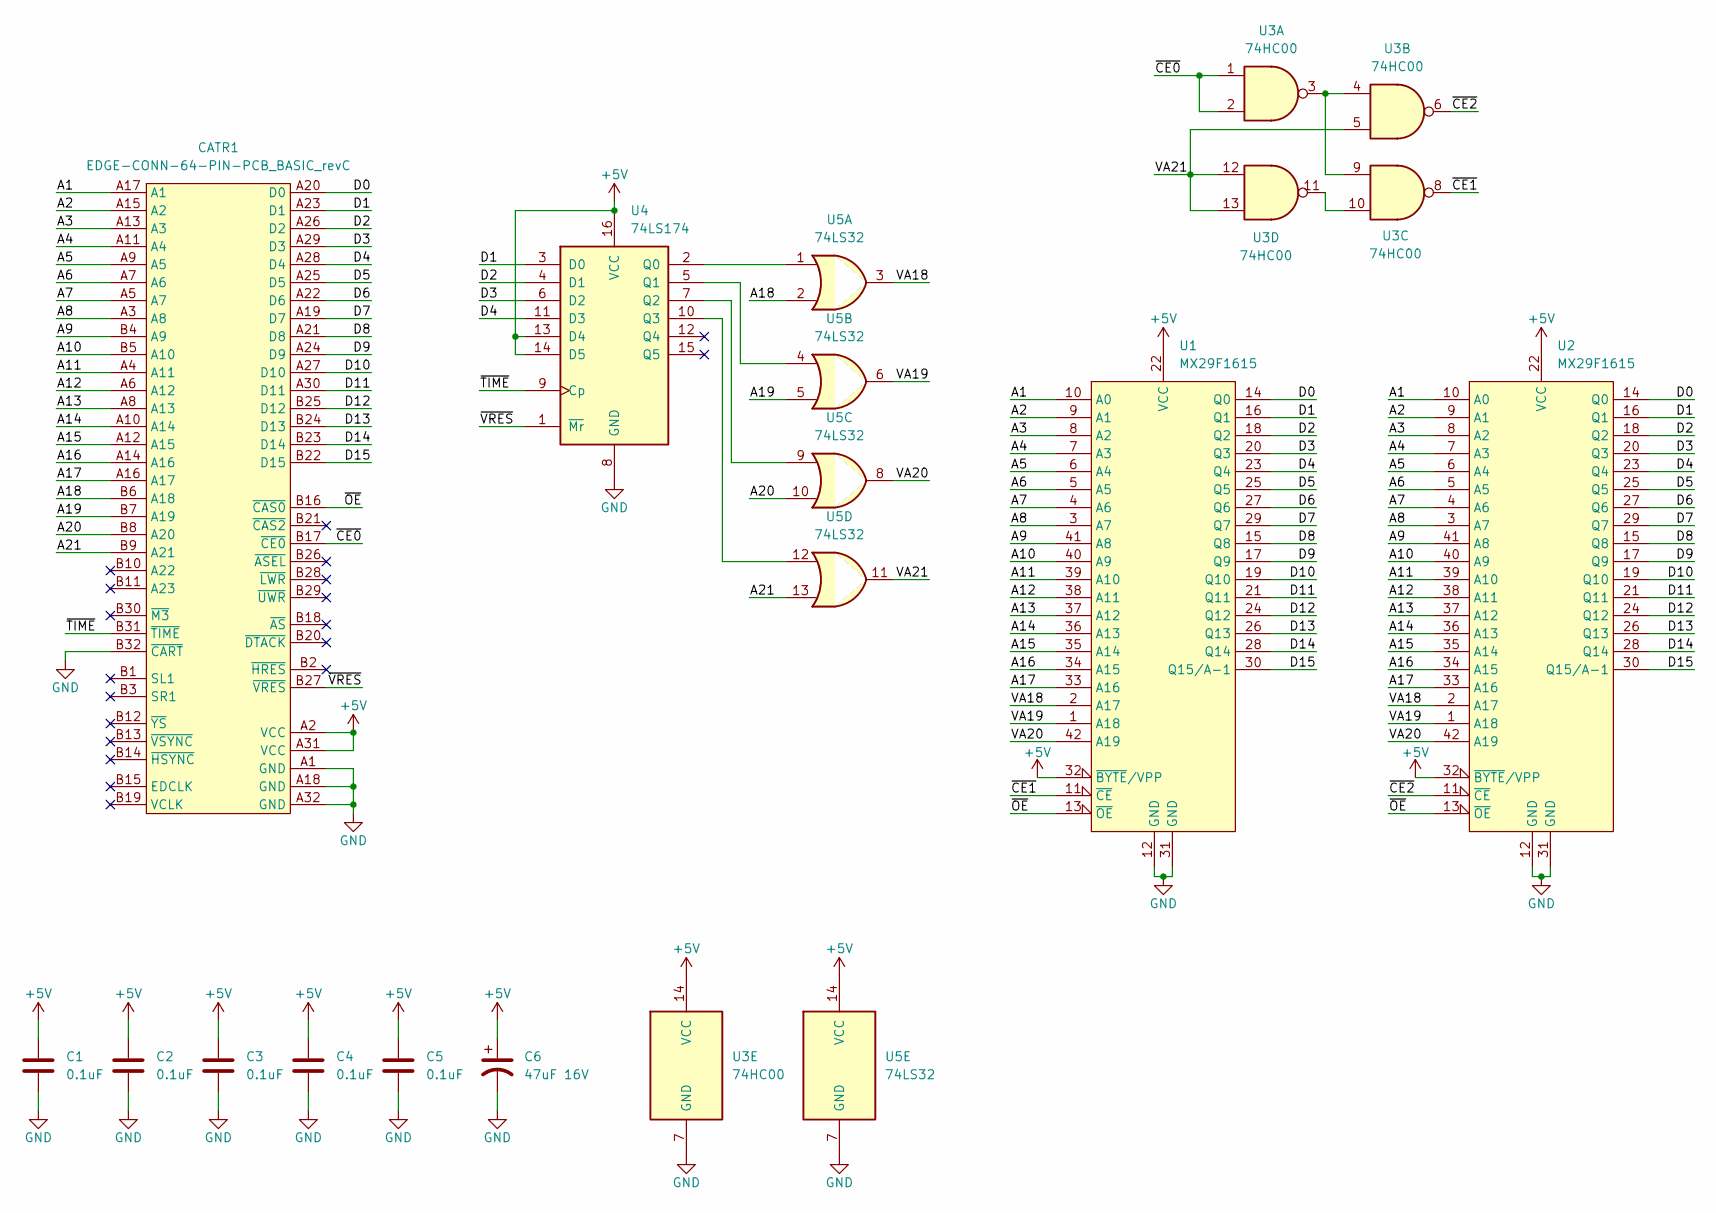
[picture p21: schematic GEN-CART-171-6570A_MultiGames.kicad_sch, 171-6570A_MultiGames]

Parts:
C1: 0.1uF; C_Axial_L3.8mm_D2.6mm_P12.50mm_Horizontal
C2, C3: 0.1uF; C_Axial_L3.8mm_D2.6mm_P10.00mm_Horizontal
C4, C5: 0.1uF; C_0805_2012Metric_Pad1.18x1.45mm_HandSolder
C6: 47uF 16V; CP_Radial_D5.0mm_P2.50mm
CATR1: EDGE-CONN-64-PIN-PCB_BASIC_revC; PCB_revC-CART-64-2.54-CONN
U1, U2: MX29F1615; DIP-42_W15.24mm
U3: 74HC00; DIP-14_W7.62mm
U4: 74LS174; SOIC-16_3.9x9.9mm_P1.27mm
U5: 74LS32; SOIC-14_3.9x8.7mm_P1.27mm

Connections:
+5V: C1.1, C2.1, C3.1, C4.1, C5.1, C6.1, CATR1.A2 (VCC), CATR1.A31 (VCC), U1.22 (VCC), U1.32 (~BYTE/VPP), U2.22 (VCC), U2.32 (~BYTE/VPP), U3.14 (VCC), U4.13 (D4), U4.14 (D5), U4.16 (VCC), U5.14 (VCC)
/A1: CATR1.A17 (A1), U1.10 (A0), U2.10 (A0)
/A2: CATR1.A15 (A2), U1.9 (A1), U2.9 (A1)
/A3: CATR1.A13 (A3), U1.8 (A2), U2.8 (A2)
/A4: CATR1.A11 (A4), U1.7 (A3), U2.7 (A3)
/A5: CATR1.A9 (A5), U1.6 (A4), U2.6 (A4)
/A6: CATR1.A7 (A6), U1.5 (A5), U2.5 (A5)
/A7: CATR1.A5 (A7), U1.4 (A6), U2.4 (A6)
/A8: CATR1.A3 (A8), U1.3 (A7), U2.3 (A7)
/A9: CATR1.B4 (A9), U1.41 (A8), U2.41 (A8)
/A10: CATR1.B5 (A10), U1.40 (A9), U2.40 (A9)
/A11: CATR1.A4 (A11), U1.39 (A10), U2.39 (A10)
/A12: CATR1.A6 (A12), U1.38 (A11), U2.38 (A11)
/A13: CATR1.A8 (A13), U1.37 (A12), U2.37 (A12)
/A14: CATR1.A10 (A14), U1.36 (A13), U2.36 (A13)
/A15: CATR1.A12 (A15), U1.35 (A14), U2.35 (A14)
/A16: CATR1.A14 (A16), U1.34 (A15), U2.34 (A15)
/A17: CATR1.A16 (A17), U1.33 (A16), U2.33 (A16)
/A18: CATR1.B6 (A18), U5.2
/A19: CATR1.B7 (A19), U5.5
/A20: CATR1.B8 (A20), U5.10
/A21: CATR1.B9 (A21), U5.13
/D0: CATR1.A20 (D0), U1.14 (Q0), U2.14 (Q0)
/D1: CATR1.A23 (D1), U1.16 (Q1), U2.16 (Q1), U4.3 (D0)
/D2: CATR1.A26 (D2), U1.18 (Q2), U2.18 (Q2), U4.4 (D1)
/D3: CATR1.A29 (D3), U1.20 (Q3), U2.20 (Q3), U4.6 (D2)
/D4: CATR1.A28 (D4), U1.23 (Q4), U2.23 (Q4), U4.11 (D3)
/D5: CATR1.A25 (D5), U1.25 (Q5), U2.25 (Q5)
/D6: CATR1.A22 (D6), U1.27 (Q6), U2.27 (Q6)
/D7: CATR1.A19 (D7), U1.29 (Q7), U2.29 (Q7)
/D8: CATR1.A21 (D8), U1.15 (Q8), U2.15 (Q8)
/D9: CATR1.A24 (D9), U1.17 (Q9), U2.17 (Q9)
/D10: CATR1.A27 (D10), U1.19 (Q10), U2.19 (Q10)
/D11: CATR1.A30 (D11), U1.21 (Q11), U2.21 (Q11)
/D12: CATR1.B25 (D12), U1.24 (Q12), U2.24 (Q12)
/D13: CATR1.B24 (D13), U1.26 (Q13), U2.26 (Q13)
/D14: CATR1.B23 (D14), U1.28 (Q14), U2.28 (Q14)
/D15: CATR1.B22 (D15), U1.30 (Q15/A-1), U2.30 (Q15/A-1)
/VA18: U1.2 (A17), U2.2 (A17), U5.3
/VA19: U1.1 (A18), U2.1 (A18), U5.6
/VA20: U1.42 (A19), U2.42 (A19), U5.8
/VA21: U3.5, U3.12, U3.13, U5.11
/~CE0: CATR1.B17 (~CE0), U3.1, U3.2
/~CE1: U1.11 (~CE), U3.8
/~CE2: U2.11 (~CE), U3.6
/~OE: CATR1.B16 (~CAS0), U1.13 (~OE), U2.13 (~OE)
/~TIME: CATR1.B31 (~TIME), U4.9 (Cp)
/~VRES: CATR1.B27 (~VRES), U4.1 (~Mr)
GND: C1.2, C2.2, C3.2, C4.2, C5.2, C6.2, CATR1.A1 (GND), CATR1.A18 (GND), CATR1.A32 (GND), CATR1.B32 (~CART), U1.12 (GND), U1.31 (GND), U2.12 (GND), U2.31 (GND), U3.7 (GND), U4.8 (GND), U5.7 (GND)
unnamed: U3.3, U3.4, U3.9
unnamed: U3.10, U3.11
unnamed: U4.2 (Q0), U5.1
unnamed: U4.5 (Q1), U5.4
unnamed: U4.7 (Q2), U5.9
unnamed: U4.10 (Q3), U5.12

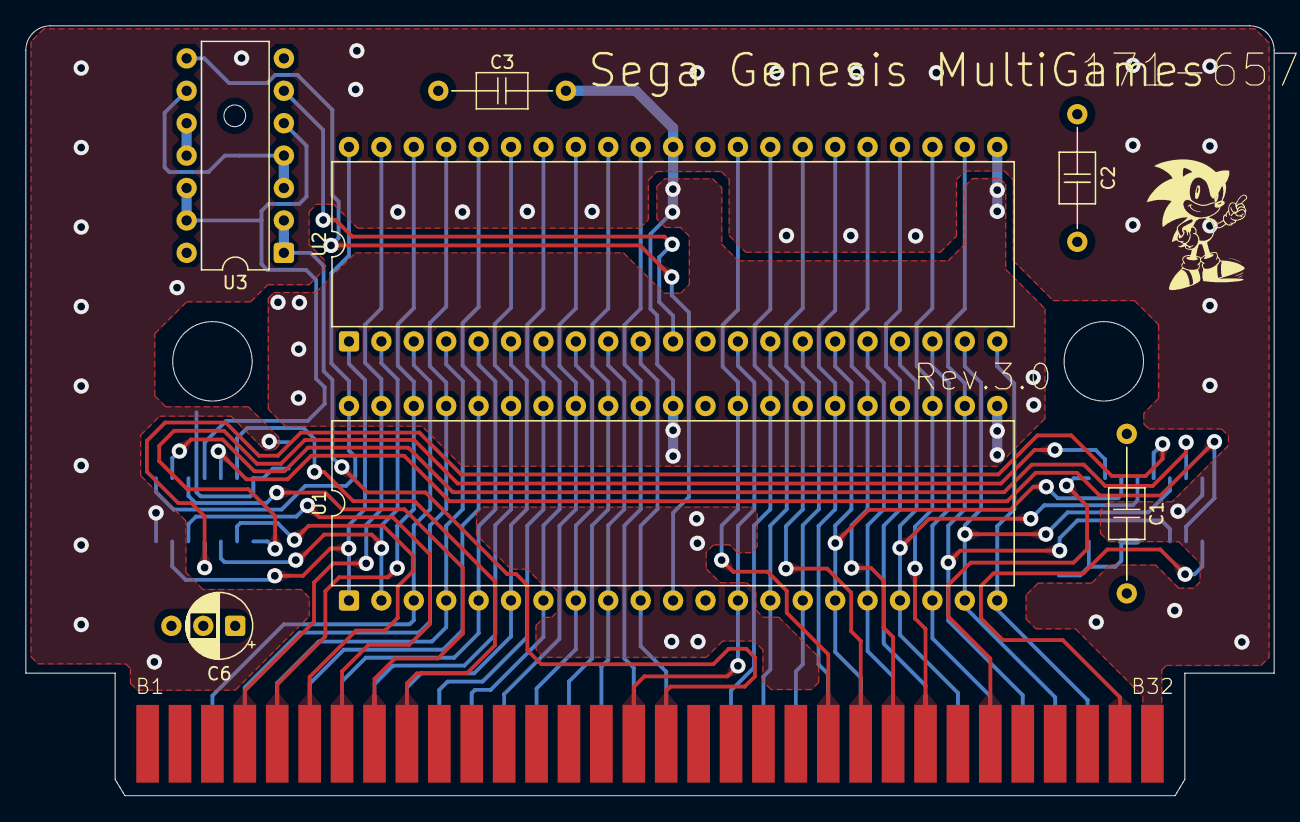
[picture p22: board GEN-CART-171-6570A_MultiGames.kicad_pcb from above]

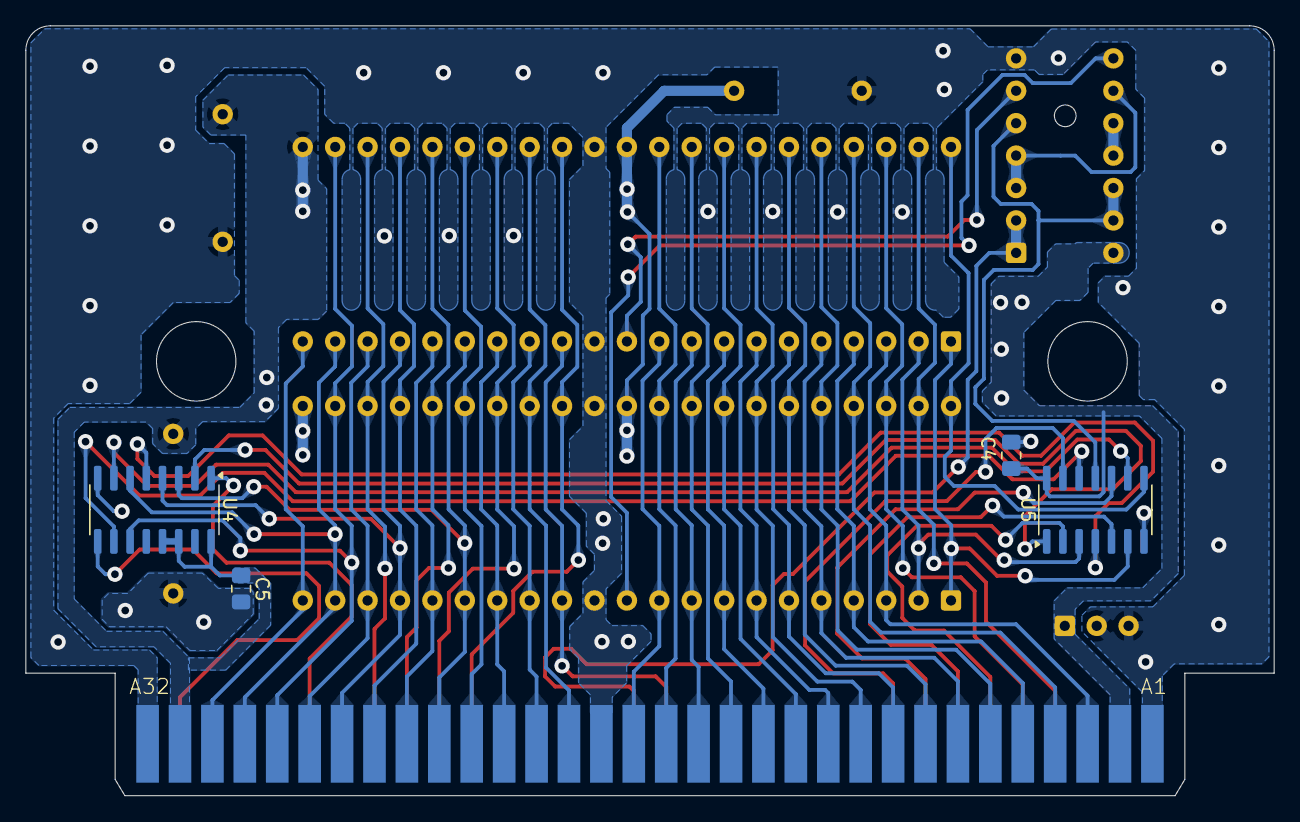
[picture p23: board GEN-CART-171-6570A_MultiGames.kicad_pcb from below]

Board: 2 copper layers, 97.8 x 60.3 mm, 12 parts (4 on the bottom side), 55 nets.

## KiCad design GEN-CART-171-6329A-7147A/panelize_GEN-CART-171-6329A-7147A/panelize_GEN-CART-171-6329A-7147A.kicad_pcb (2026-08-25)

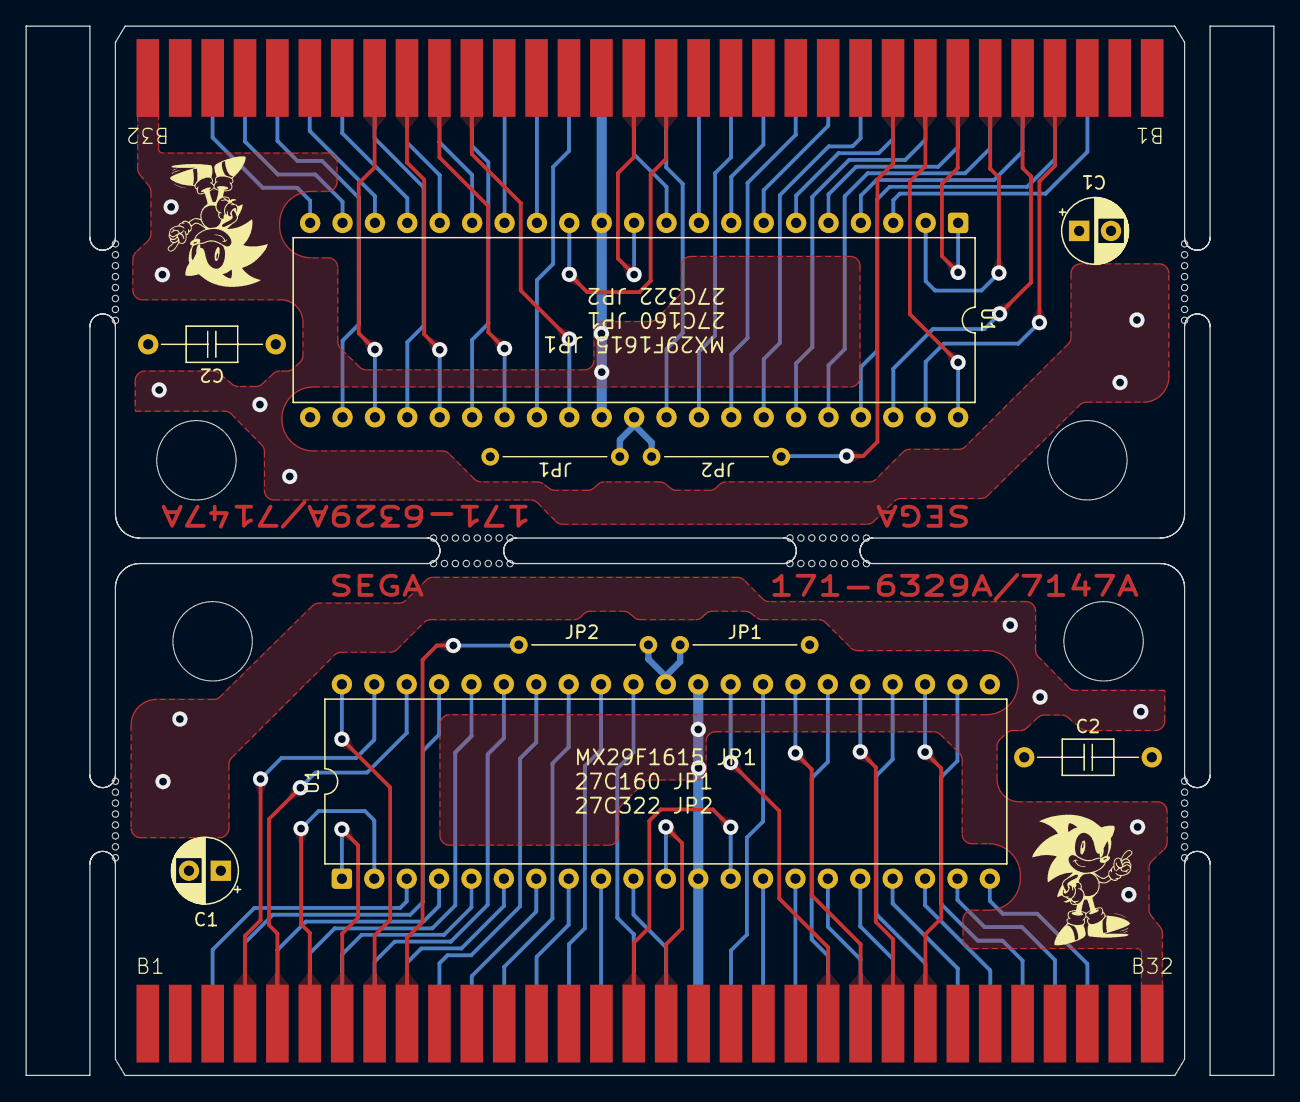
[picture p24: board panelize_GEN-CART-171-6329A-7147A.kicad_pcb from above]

Board: 2 copper layers, 97.8 x 82.3 mm, 76 parts (0 on the bottom side), 84 nets.

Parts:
C1, C1#2: 47uF 16V; CP_Radial_D5.0mm_P2.50mm
C2, C2#2: 0.1uF; C_Axial_L3.8mm_D2.6mm_P10.00mm_Horizontal
CATR1, CATR1#2: EDGE-CONN-64-PIN-PCB_BASIC_revA; PCB_revA-CART-64-2.54-CONN
JP1, JP1#2, JP2, JP2#2: Jumper_2_Open; Jumper_P10.16mm_D0.7mm
KiKit_MB_1_1, KiKit_MB_1_2, KiKit_MB_1_3, KiKit_MB_1_4, KiKit_MB_1_5, KiKit_MB_1_6, KiKit_MB_1_7, KiKit_MB_1_8, KiKit_MB_2_1, KiKit_MB_2_2, KiKit_MB_2_3, KiKit_MB_2_4, KiKit_MB_2_5, KiKit_MB_2_6, KiKit_MB_2_7, KiKit_MB_2_8, KiKit_MB_3_1, KiKit_MB_3_2, KiKit_MB_3_3, KiKit_MB_3_4, KiKit_MB_3_5, KiKit_MB_3_6, KiKit_MB_3_7, KiKit_MB_3_8, KiKit_MB_4_1, KiKit_MB_4_2, KiKit_MB_4_3, KiKit_MB_4_4, KiKit_MB_4_5, KiKit_MB_4_6, KiKit_MB_4_7, KiKit_MB_4_8, KiKit_MB_5_1, KiKit_MB_5_2, KiKit_MB_5_3, KiKit_MB_5_4, KiKit_MB_5_5, KiKit_MB_5_6, KiKit_MB_5_7, KiKit_MB_5_8, KiKit_MB_6_1, KiKit_MB_6_2, KiKit_MB_6_3, KiKit_MB_6_4, KiKit_MB_6_5, KiKit_MB_6_6, KiKit_MB_6_7, KiKit_MB_6_8, KiKit_MB_7_1, KiKit_MB_7_2, KiKit_MB_7_3, KiKit_MB_7_4, KiKit_MB_7_5, KiKit_MB_7_6, KiKit_MB_7_7, KiKit_MB_7_8, KiKit_MB_8_1, KiKit_MB_8_2, KiKit_MB_8_3, KiKit_MB_8_4, KiKit_MB_8_5, KiKit_MB_8_6, KiKit_MB_8_7, KiKit_MB_8_8: NPTH
U1, U1#2: MX29F1615; DIP-42_W15.24mm

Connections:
Board_0-+5V: C1#2.1, C2.1, CATR1#2.A2 (VCC), CATR1#2.A31 (VCC), JP1.2 (B), U1#2.22 (VCC)
Board_0-/A1: CATR1#2.A17 (A1), U1#2.10 (A0)
Board_0-/A2: CATR1#2.A15 (A2), U1#2.9 (A1)
Board_0-/A3: CATR1#2.A13 (A3), U1#2.8 (A2)
Board_0-/A4: CATR1#2.A11 (A4), U1#2.7 (A3)
Board_0-/A5: CATR1#2.A9 (A5), U1#2.6 (A4)
Board_0-/A6: CATR1#2.A7 (A6), U1#2.5 (A5)
Board_0-/A7: CATR1#2.A5 (A7), U1#2.4 (A6)
Board_0-/A8: CATR1#2.A3 (A8), U1#2.3 (A7)
Board_0-/A9: CATR1#2.B4 (A9), U1#2.41 (A8)
Board_0-/A10: CATR1#2.B5 (A10), U1#2.40 (A9)
Board_0-/A11: CATR1#2.A4 (A11), U1#2.39 (A10)
Board_0-/A12: CATR1#2.A6 (A12), U1#2.38 (A11)
Board_0-/A13: CATR1#2.A8 (A13), U1#2.37 (A12)
Board_0-/A14: CATR1#2.A10 (A14), U1#2.36 (A13)
Board_0-/A15: CATR1#2.A12 (A15), U1#2.35 (A14)
Board_0-/A16: CATR1#2.A14 (A16), U1#2.34 (A15)
Board_0-/A17: CATR1#2.A16 (A17), U1#2.33 (A16)
Board_0-/A18: CATR1#2.B6 (A18), U1#2.2 (A17)
Board_0-/A19: CATR1#2.B7 (A19), U1#2.1 (A18)
Board_0-/A20: CATR1#2.B8 (A20), U1#2.42 (A19)
Board_0-/A21: CATR1#2.B9 (A21), JP2#2.1 (A)
Board_0-/D0: CATR1#2.A20 (D0), U1#2.14 (Q0)
Board_0-/D1: CATR1#2.A23 (D1), U1#2.16 (Q1)
Board_0-/D2: CATR1#2.A26 (D2), U1#2.18 (Q2)
Board_0-/D3: CATR1#2.A29 (D3), U1#2.20 (Q3)
Board_0-/D4: CATR1#2.A28 (D4), U1#2.23 (Q4)
Board_0-/D5: CATR1#2.A25 (D5), U1#2.25 (Q5)
Board_0-/D6: CATR1#2.A22 (D6), U1#2.27 (Q6)
Board_0-/D7: CATR1#2.A19 (D7), U1#2.29 (Q7)
Board_0-/D8: CATR1#2.A21 (D8), U1#2.15 (Q8)
Board_0-/D9: CATR1#2.A24 (D9), U1#2.17 (Q9)
Board_0-/D10: CATR1#2.A27 (D10), U1#2.19 (Q10)
Board_0-/D11: CATR1#2.A30 (D11), U1#2.21 (Q11)
Board_0-/D12: CATR1#2.B25 (D12), U1#2.24 (Q12)
Board_0-/D13: CATR1#2.B24 (D13), U1#2.26 (Q13)
Board_0-/D14: CATR1#2.B23 (D14), U1#2.28 (Q14)
Board_0-/D15: CATR1#2.B22 (D15), U1#2.30 (Q15/A-1)
Board_0-//CE: CATR1#2.B17 (~CE0), U1#2.11 (~CE)
Board_0-//OE: CATR1#2.B16 (~CAS0), U1#2.13 (~OE)
Board_0-GND: C1#2.2, C2.2, CATR1#2.A1 (GND), CATR1#2.A18 (GND), CATR1#2.A32 (GND), CATR1#2.B32 (~CART), U1#2.12 (GND), U1#2.31 (GND)
Board_0-Net-(JP1-A): JP1.1 (A), JP2#2.2 (B), U1#2.32 (~BYTE/VPP)
Board_1-+5V: C1.1, C2#2.1, CATR1.A2 (VCC), CATR1.A31 (VCC), JP1#2.2 (B), U1.22 (VCC)
Board_1-/A1: CATR1.A17 (A1), U1.10 (A0)
Board_1-/A2: CATR1.A15 (A2), U1.9 (A1)
Board_1-/A3: CATR1.A13 (A3), U1.8 (A2)
Board_1-/A4: CATR1.A11 (A4), U1.7 (A3)
Board_1-/A5: CATR1.A9 (A5), U1.6 (A4)
Board_1-/A6: CATR1.A7 (A6), U1.5 (A5)
Board_1-/A7: CATR1.A5 (A7), U1.4 (A6)
Board_1-/A8: CATR1.A3 (A8), U1.3 (A7)
Board_1-/A9: CATR1.B4 (A9), U1.41 (A8)
Board_1-/A10: CATR1.B5 (A10), U1.40 (A9)
Board_1-/A11: CATR1.A4 (A11), U1.39 (A10)
Board_1-/A12: CATR1.A6 (A12), U1.38 (A11)
Board_1-/A13: CATR1.A8 (A13), U1.37 (A12)
Board_1-/A14: CATR1.A10 (A14), U1.36 (A13)
Board_1-/A15: CATR1.A12 (A15), U1.35 (A14)
Board_1-/A16: CATR1.A14 (A16), U1.34 (A15)
Board_1-/A17: CATR1.A16 (A17), U1.33 (A16)
Board_1-/A18: CATR1.B6 (A18), U1.2 (A17)
Board_1-/A19: CATR1.B7 (A19), U1.1 (A18)
Board_1-/A20: CATR1.B8 (A20), U1.42 (A19)
Board_1-/A21: CATR1.B9 (A21), JP2.1 (A)
Board_1-/D0: CATR1.A20 (D0), U1.14 (Q0)
Board_1-/D1: CATR1.A23 (D1), U1.16 (Q1)
Board_1-/D2: CATR1.A26 (D2), U1.18 (Q2)
Board_1-/D3: CATR1.A29 (D3), U1.20 (Q3)
Board_1-/D4: CATR1.A28 (D4), U1.23 (Q4)
Board_1-/D5: CATR1.A25 (D5), U1.25 (Q5)
Board_1-/D6: CATR1.A22 (D6), U1.27 (Q6)
Board_1-/D7: CATR1.A19 (D7), U1.29 (Q7)
Board_1-/D8: CATR1.A21 (D8), U1.15 (Q8)
Board_1-/D9: CATR1.A24 (D9), U1.17 (Q9)
Board_1-/D10: CATR1.A27 (D10), U1.19 (Q10)
Board_1-/D11: CATR1.A30 (D11), U1.21 (Q11)
Board_1-/D12: CATR1.B25 (D12), U1.24 (Q12)
Board_1-/D13: CATR1.B24 (D13), U1.26 (Q13)
Board_1-/D14: CATR1.B23 (D14), U1.28 (Q14)
Board_1-/D15: CATR1.B22 (D15), U1.30 (Q15/A-1)
Board_1-//CE: CATR1.B17 (~CE0), U1.11 (~CE)
Board_1-//OE: CATR1.B16 (~CAS0), U1.13 (~OE)
Board_1-GND: C1.2, C2#2.2, CATR1.A1 (GND), CATR1.A18 (GND), CATR1.A32 (GND), CATR1.B32 (~CART), U1.12 (GND), U1.31 (GND)
Board_1-Net-(JP1-A): JP1#2.1 (A), JP2.2 (B), U1.32 (~BYTE/VPP)
